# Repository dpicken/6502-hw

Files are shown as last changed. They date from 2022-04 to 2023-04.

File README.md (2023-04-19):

# 6502-hw

Schematics and PCBs for a [Ben Eater](https://eater.net/6502) inspired 6502 computer.

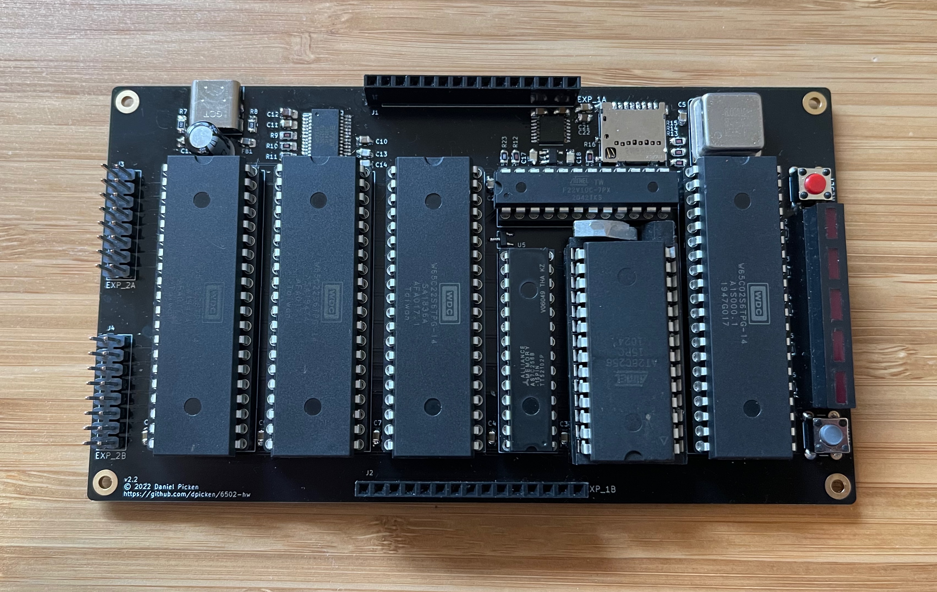
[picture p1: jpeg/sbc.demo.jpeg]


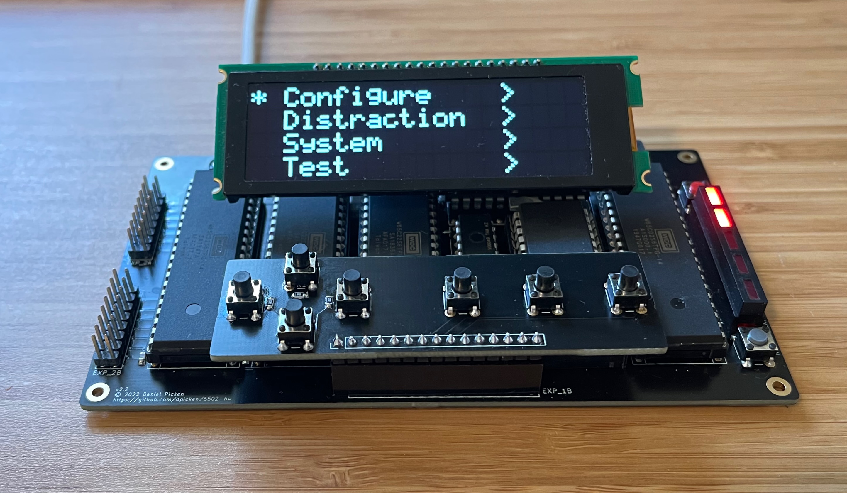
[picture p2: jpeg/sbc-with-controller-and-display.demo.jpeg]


## SBC

The single board computer ([schematic](/pdf/sbc.pdf), [layout](pdf/sbc.pcb.pdf), [BOM](bom/sbc.md)), features include:

  - 65C02 CPU, 8 MHz (with a suitable EEPROM)
  - ATF22V10C PLD (address space decode and IRQ glue)
  - 32 KiB ROM
  - 32 KiB RAM
  - 32 GiB microSD mass storage
  - 3 VIAs (1 system, 2 user accessible)
  - USB serial

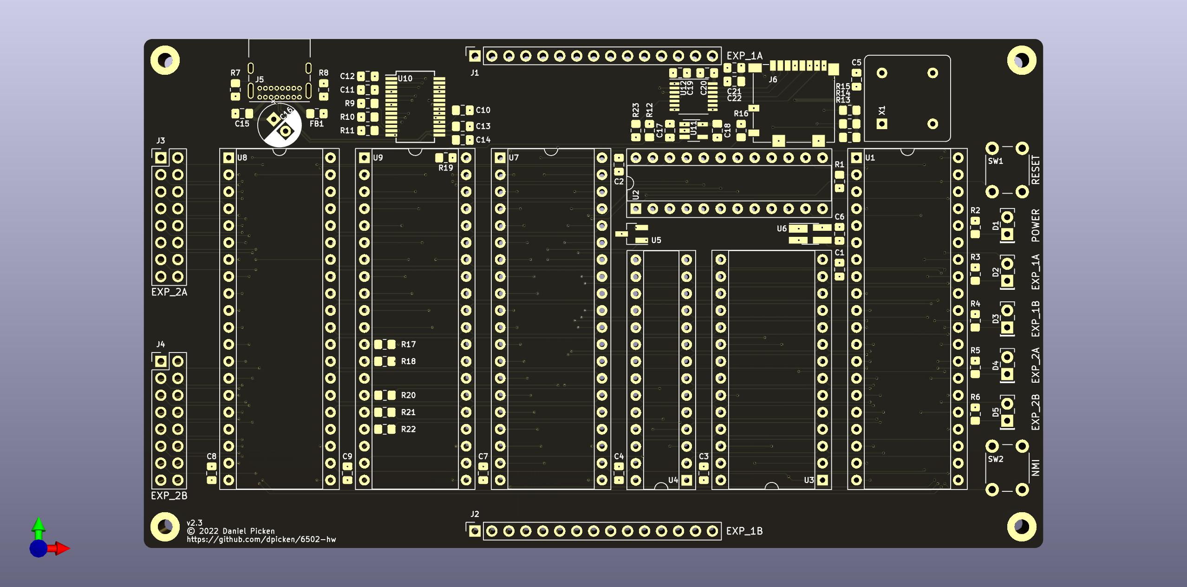
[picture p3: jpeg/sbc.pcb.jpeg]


### Programmable Logic

Install [rust](https://www.rust-lang.org/tools/install), then install galette:

```
git clone https://github.com/simon-frankau/galette
bash -c "cd galette; cargo build --release"
cp galette/target/release/galette ~/bin
```

Clone the fab build system and the 6502-hw project:

```
git clone https://github.com/dpicken/fab
git clone https://github.com/dpicken/6502-hw
```

Build:

```
cd 6502-hw
make
```

Write ATF22v10C:

```
make install
```

### Software

- See [dpicken/6502-os](https://github.com/dpicken/6502-os).

## SBC Controller

A controller for the single board computer ([schematic](/pdf/sbc-exp-control.pdf), [layout](pdf/sbc-exp-control.pcb.pdf), [BOM](bom/sbc-exp-control.md)).

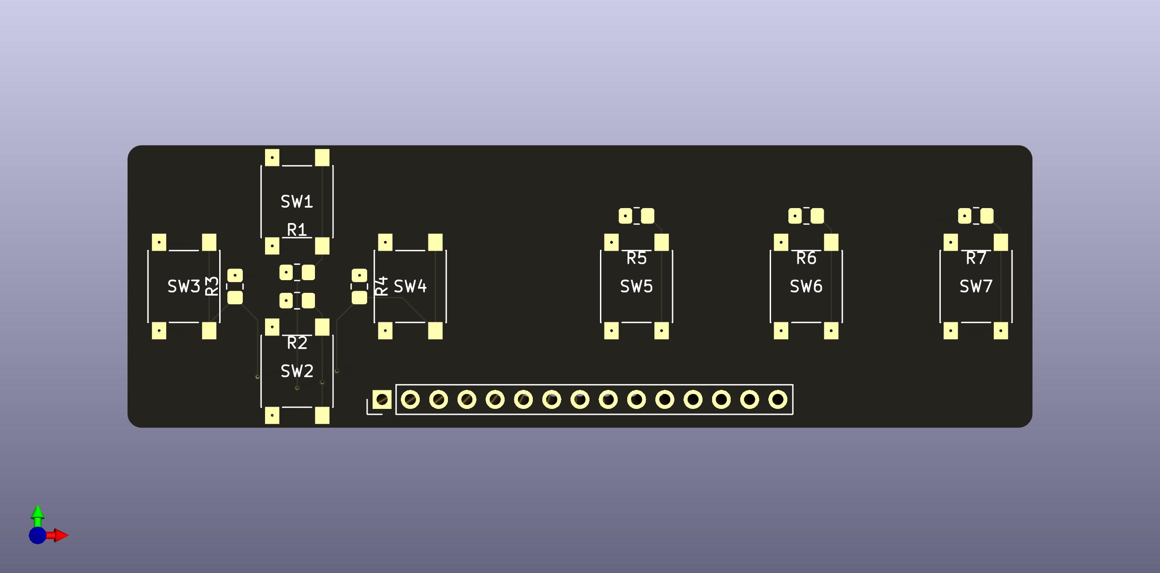
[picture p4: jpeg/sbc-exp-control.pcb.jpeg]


## SBC Display - 20x4 OLED character module

An OLED display for the single board computer ([schematic](/pdf/sbc-exp-nhd_0420cw-interposer.pdf), [layout](pdf/sbc-exp-nhd_0420cw-interposer.pcb.pdf), [BOM](bom/sbc-exp-nhd_0420cw-interposer.md)).

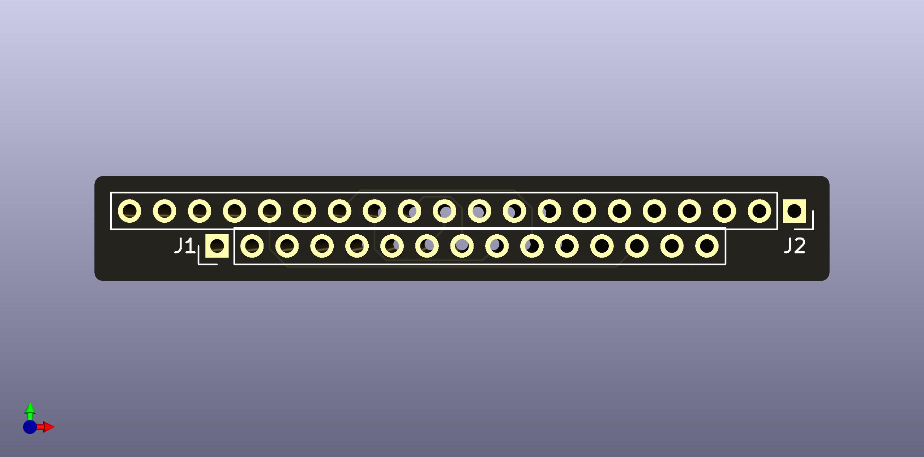
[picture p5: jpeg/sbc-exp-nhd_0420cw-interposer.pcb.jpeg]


## SBC Display - 40x4 or 20x4 LCD character module

An LCD display for the single board computer ([schematic](/pdf/sbc-exp-erm4004_erm2004-interposer.pdf), [layout](pdf/sbc-exp-erm4004_erm2004-interposer.pcb.pdf), [BOM](bom/sbc-exp-erm4004_erm2004-interposer.md)).

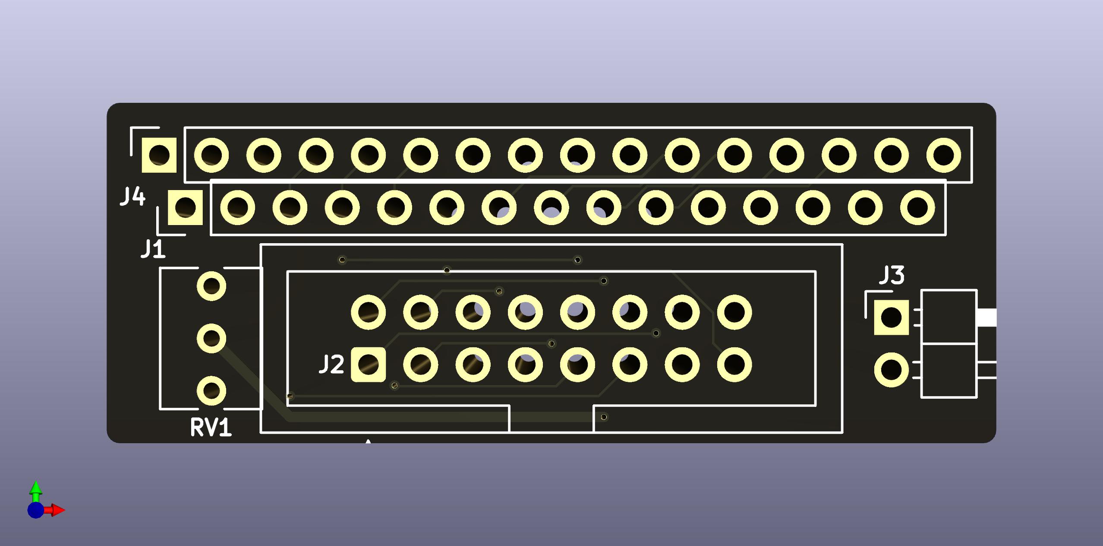
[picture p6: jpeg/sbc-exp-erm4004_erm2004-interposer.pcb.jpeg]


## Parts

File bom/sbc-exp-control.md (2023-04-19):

# SBC Controller BOM

|References|Quantity|Description|
|-|-|-|
|J1|1|1x15 pin header, 2.54mm|
|SW1, SW2, SW3, SW4, SW5, SW6, SW7|7|[6mm tactile switch, SMT](https://www.amazon.com/dp/B07HCFM3H1)|
|R1, R2, R3, R4, R5, R6, R7|7|[1K resistor, 0805](https://www.digikey.com/en/products/detail/cts-resistor-products/77081102P/1000658)|

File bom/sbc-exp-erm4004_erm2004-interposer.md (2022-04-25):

# SBC Display - 40x4 or 20x4 LCD character module BOM

|References|Quantity|Description|
|-|-|-|
|J1|1|1x15 pin header, 2.54mm|
|J2|1|2x8 pin header, 2.54mm|
|J3|1|1x2 pin header, 2.54mm|
|J4|1|1x16 pin socket, 2.54mm|
|V0|1|[10K potentiometer](https://www.digikey.com/en/products/detail/tt-electronics-bi/91WR10KLF/6155632)|
||1|[20x4 ERM2004 LCD character module](https://www.buydisplay.com/small-size-blue-lcd-bezel-20x4-arduino-library-character-display-module)|
||1|[40x4 ERM4004 LCD character module](https://www.buydisplay.com/character-arduino-40x4-lcd-display-datasheet-ks0066-white-on-blue)||
||1|1x16 pin header, 2.54mm, for ERM2004|
||1|[2 pin female to female ribbon cable, 2.54mm](https://www.amazon.com/gp/product/B07FM73YN9), for ERM4004|
||1|[16 pin female to female IDC ribbon cable, 2.54mm](https://www.amazon.com/gp/product/B07FKRYJVR), for ERM4004||

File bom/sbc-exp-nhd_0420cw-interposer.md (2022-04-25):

# SBC Display - 20x4 OLED character module BOM

|References|Quantity|Description|
|-|-|-|
|J1|1|1x15 pin header, 2.54mm|
|J2|1|1x20 pin socket, 2.54mm|
|-|1|[20x4 NHD-0402CW OLED character module](https://www.digikey.com/en/products/detail/newhaven-display-intl/NHD-0420CW-AW3/7942051)|
|-|1|1x20 pin header, 2.54mm, for NHD-0420CW|

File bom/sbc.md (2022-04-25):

# SBC BOM

|References|Quantity|Description|
|-|-|-|
|C1, C3, C4, C5, C6, C7, C8, C9, C10, C11, C19, C20, C21|13|[0.1uF MLCC capacitor, 0805](https://www.mouser.com/ProductDetail/80-C0805C104J1RECAUT)|
|C2|1|[0.22uF MLCC capacitor, 0805](https://www.mouser.com/ProductDetail/80-C0805C224J1RECAUT)|
|C12, C22|2|[4.7uF MLCC capacitor, 0805](https://www.mouser.com/ProductDetail/80-C0805C475K3RAUTO)|
|C13, C14|2|[47pF MLCC capacitor, 0805](https://www.mouser.com/ProductDetail/80-C0805C470J1GAUTO)|
|C15|1|[10nF MLCC capacitor, 0805](https://www.mouser.com/ProductDetail/80-C0805C103J1GECTU)|
|C16|1|[220uF electrolytic capacitor, 6.3mm](https://www.digikey.com/en/products/detail/panasonic-electronic-components/ECE-A0JKA221/44725)|
|C17, C18|2|[1uF MLCC capacitor, 0805](https://www.mouser.com/ProductDetail/80-C0805C105K5R)|
|D1, D2, D3, D4, D5|1|[5 segment LED array](https://www.mouser.com/ProductDetail/Lumex/SSA-LXB525ID?qs=K%252Bxkc0srH7Bjt6LUAQzTgQ%3D%3D)|
|FB1|1|[Ferrite Bead, 0805](https://www.mouser.com/ProductDetail/652-MH2029-400Y)|
|J1, J2|2|[1x15 pin socket, 2.54mm](https://www.amazon.com/gp/product/B07VP63Z78)|
|J3, J4|2|[2x8 pin header, 2.54mm](https://www.mouser.com/ProductDetail/649-67996-416HLF)|
|J5|1|[USB Type-C receptacle](https://www.mouser.com/ProductDetail/640-USB4085-GF-A)|
|J6|1|[microSD socket](https://www.mouser.com/ProductDetail/538-104031-0811)|
|R1|1|[3K resistor, 0805](https://www.mouser.com/ProductDetail/667-ERJ-P06J302V)|
|R2, R3, R4, R5, R6|5|[150R resistor, 0805](https://www.mouser.com/ProductDetail/667-ERJ-P06F1600V)|
|R7, R8|2|[5.1K resistor, 0805](https://www.mouser.com/ProductDetail/667-ERJ-P06J512V)|
|R9, R10, R11, R12, R13, R14, R15, R16|8|[10K resistor, 0805](https://www.mouser.com/ProductDetail/667-ERJ-UP6J103V)|
|R17, R18, R19, R20, R21, R22, R23|7|[30R resistor, 0805](https://www.mouser.com/ProductDetail/667-ERJ-P06J330V)|
|SW1|1|[6mm tactile switch, red](https://www.digikey.com/en/products/detail/c-k/PTS645SK43-2-LFS/1146784)|
|SW2|1|[6mm tactile switch, gray](https://www.digikey.com/en/products/detail/c-k/PTS645SH43-2-LFS/3861368)|
|U1|1|[WD65C02](https://www.jameco.com/z/W65C02S6TPG-14-Western-Design-Center-MPU-8-Bit-14MHz-65KB-Memory-40-Pin-PDIP_2143638.html), [IC socket](https://www.mouser.com/ProductDetail/575-199640)|
|U2|1|[ATF22V10C-7PX](https://www.mouser.com/ProductDetail/556-AF22V10C7PX), [IC socket](https://www.mouser.com/ProductDetail/80-C0805C105K5R)|
|U3|1|[AT28C256-15PU](https://www.digikey.com/en/products/detail/microchip-technology/AT28C256-15PU/1008506), [IC socket](https://www.mouser.com/ProductDetail/575-199628)|
|U4|1|[AS7C256B-15PIN](https://www.digikey.com/en/products/detail/alliance-memory-inc/AS7C256B-15PIN/4498986), [IC socket](https://www.mouser.com/ProductDetail/575-199328)|
|U5|1|[DS1813R](https://www.mouser.com/ProductDetail/700-DS1813R-5TR)|
|U6|1|[MAX6816](https://www.ebay.com/itm/10pcs-MAX6816EUS-T-MAX-6816-EUS-T-Integrated-Circuit-IC-/174489807094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)|
|U7, U8, U9|3|[WD65C22](https://www.jameco.com/z/W65C22S6TPG-14-Western-Design-Center-Versatile-Interface-Adapter-via-8-Bit-I-O-Ports-14-MHz-40-Pin-PDIP-CMOS-5-Volt_2143591.html), [IC socket](https://www.mouser.com/ProductDetail/575-199640)|
|U10|1|[RT245RL](https://www.mouser.com/ProductDetail/895-FT245RL-TUBE)|
|U11|1|[LD39015M33R](https://www.mouser.com/ProductDetail/511-LD39015M33R)|
|U12|1|[TXU0304PWR](https://www.mouser.com/ProductDetail/595-TXU0304PWR)|
|X1|1|[8MHz oscillator, half-can](https://www.mouser.com/ProductDetail/520-TCH800-X)|

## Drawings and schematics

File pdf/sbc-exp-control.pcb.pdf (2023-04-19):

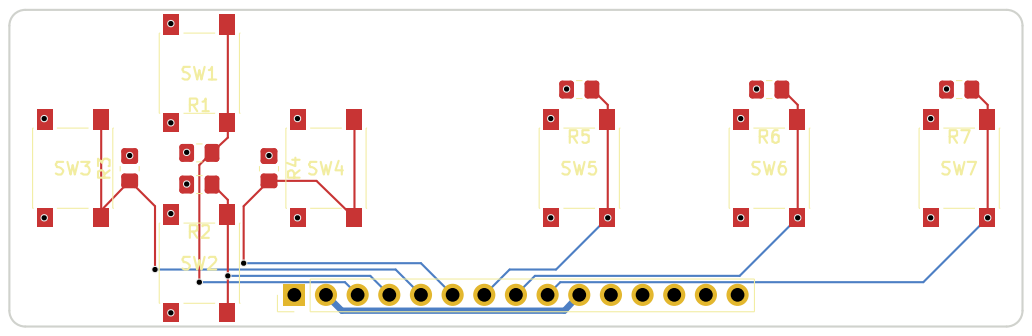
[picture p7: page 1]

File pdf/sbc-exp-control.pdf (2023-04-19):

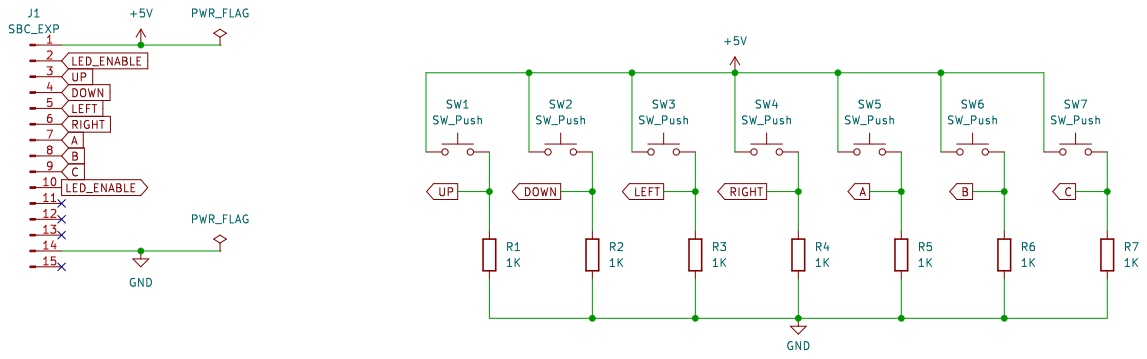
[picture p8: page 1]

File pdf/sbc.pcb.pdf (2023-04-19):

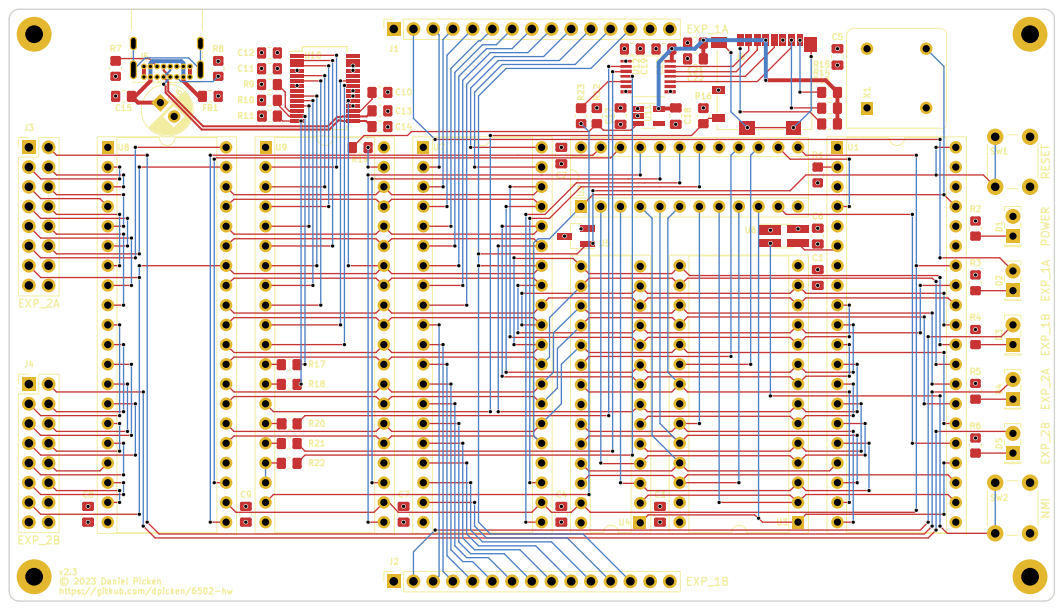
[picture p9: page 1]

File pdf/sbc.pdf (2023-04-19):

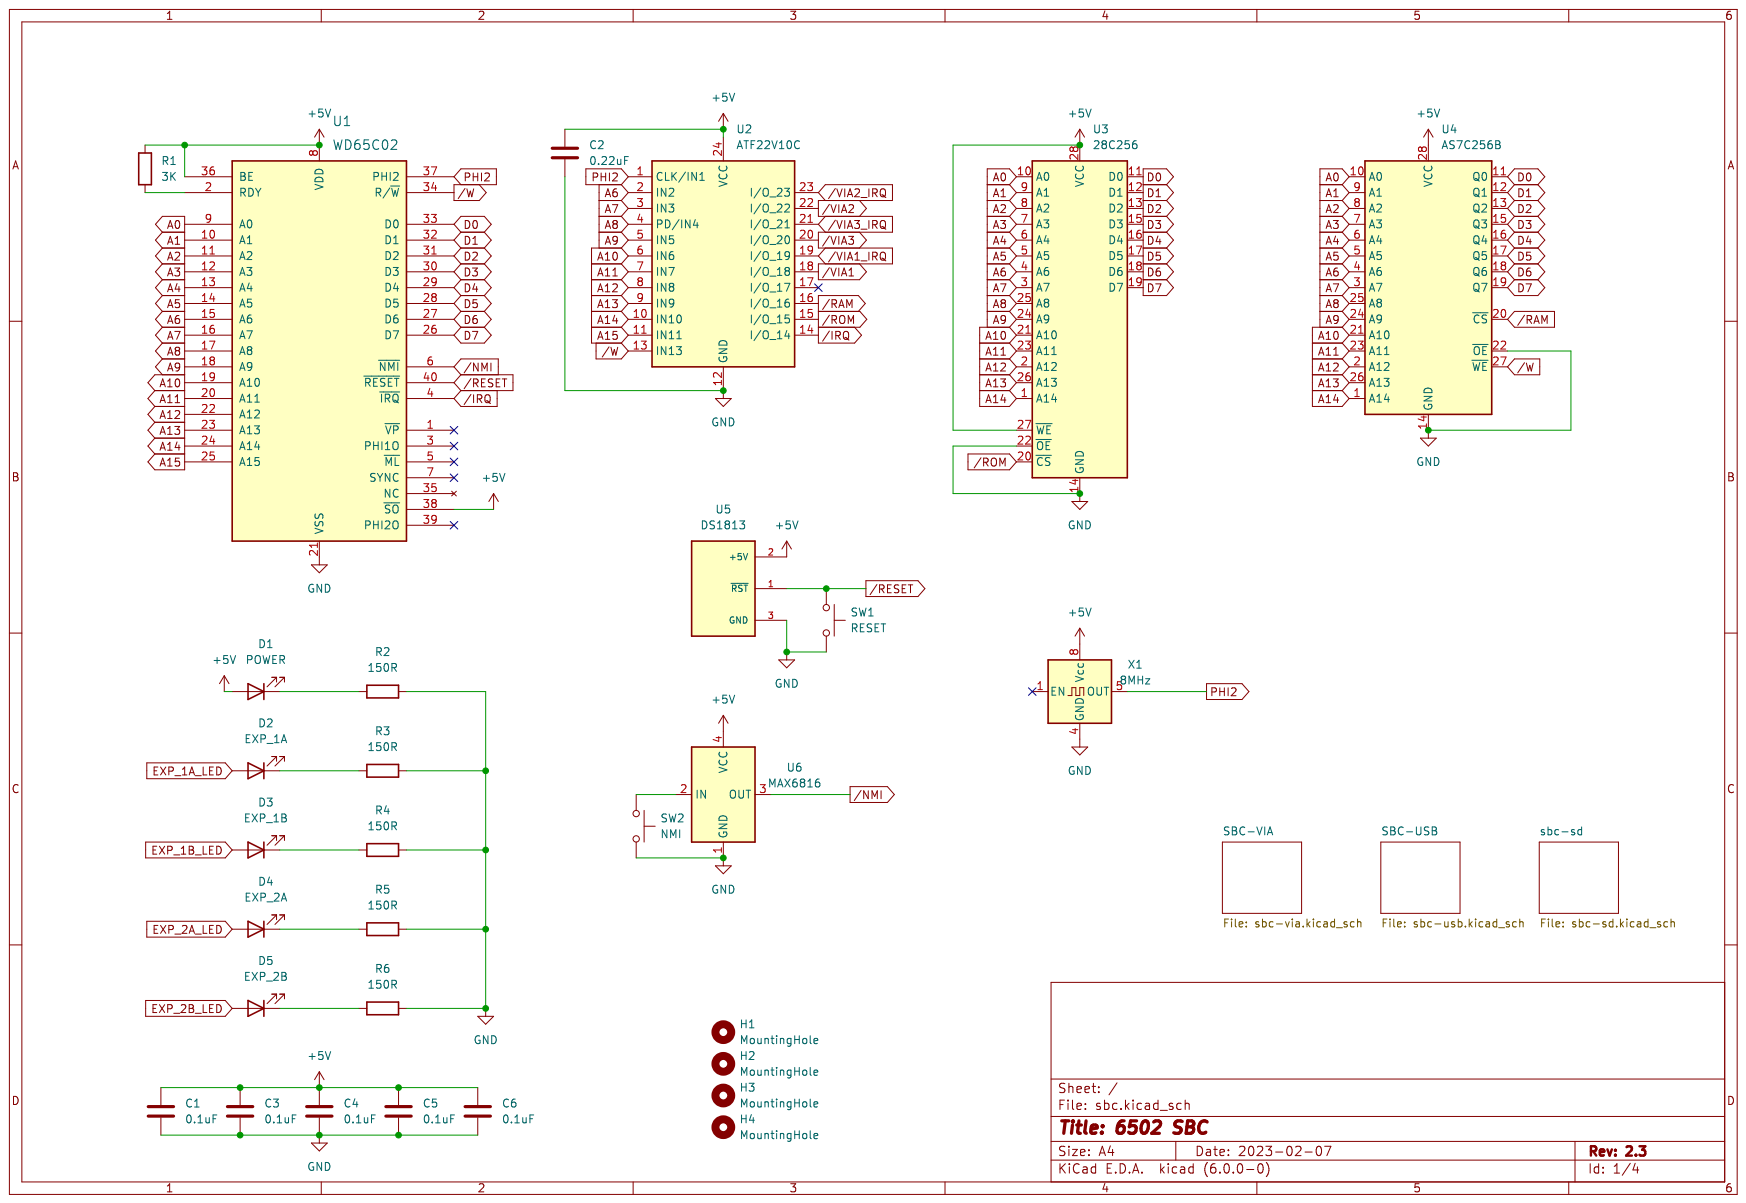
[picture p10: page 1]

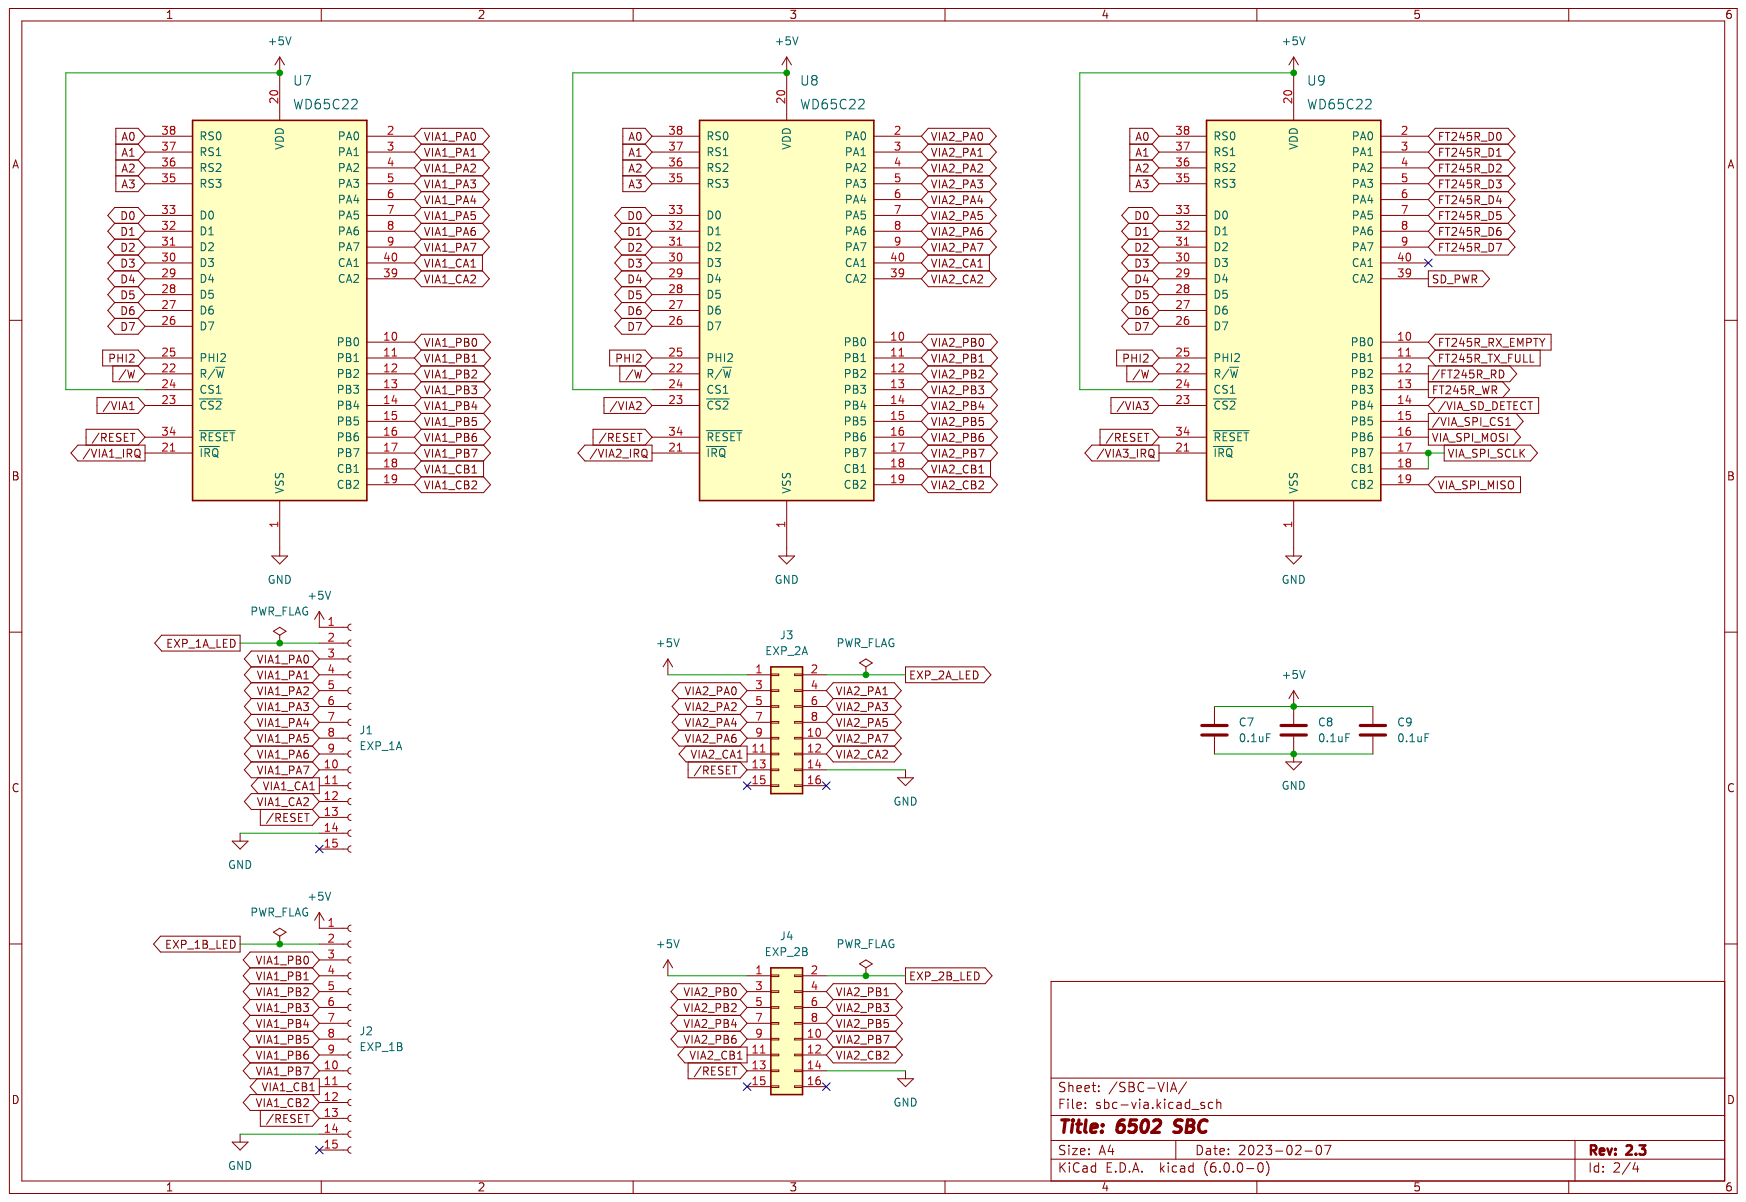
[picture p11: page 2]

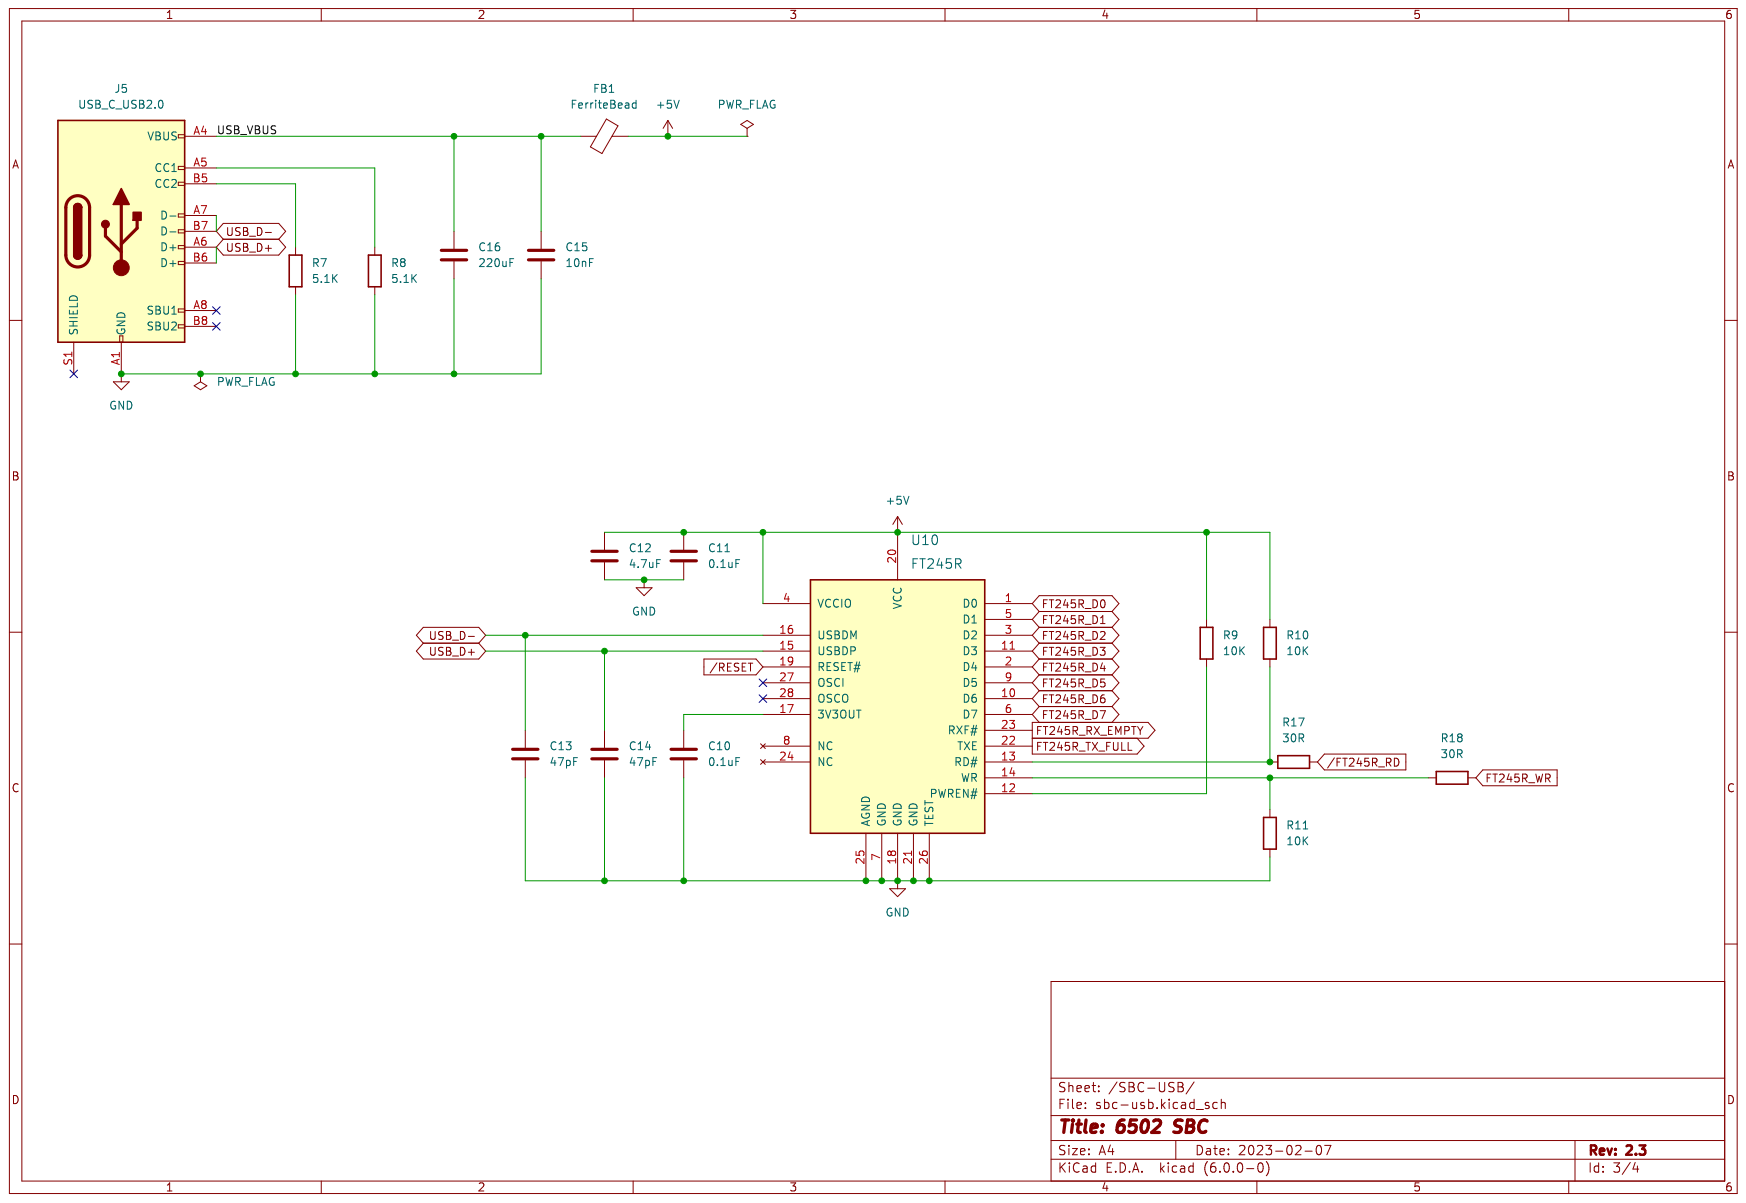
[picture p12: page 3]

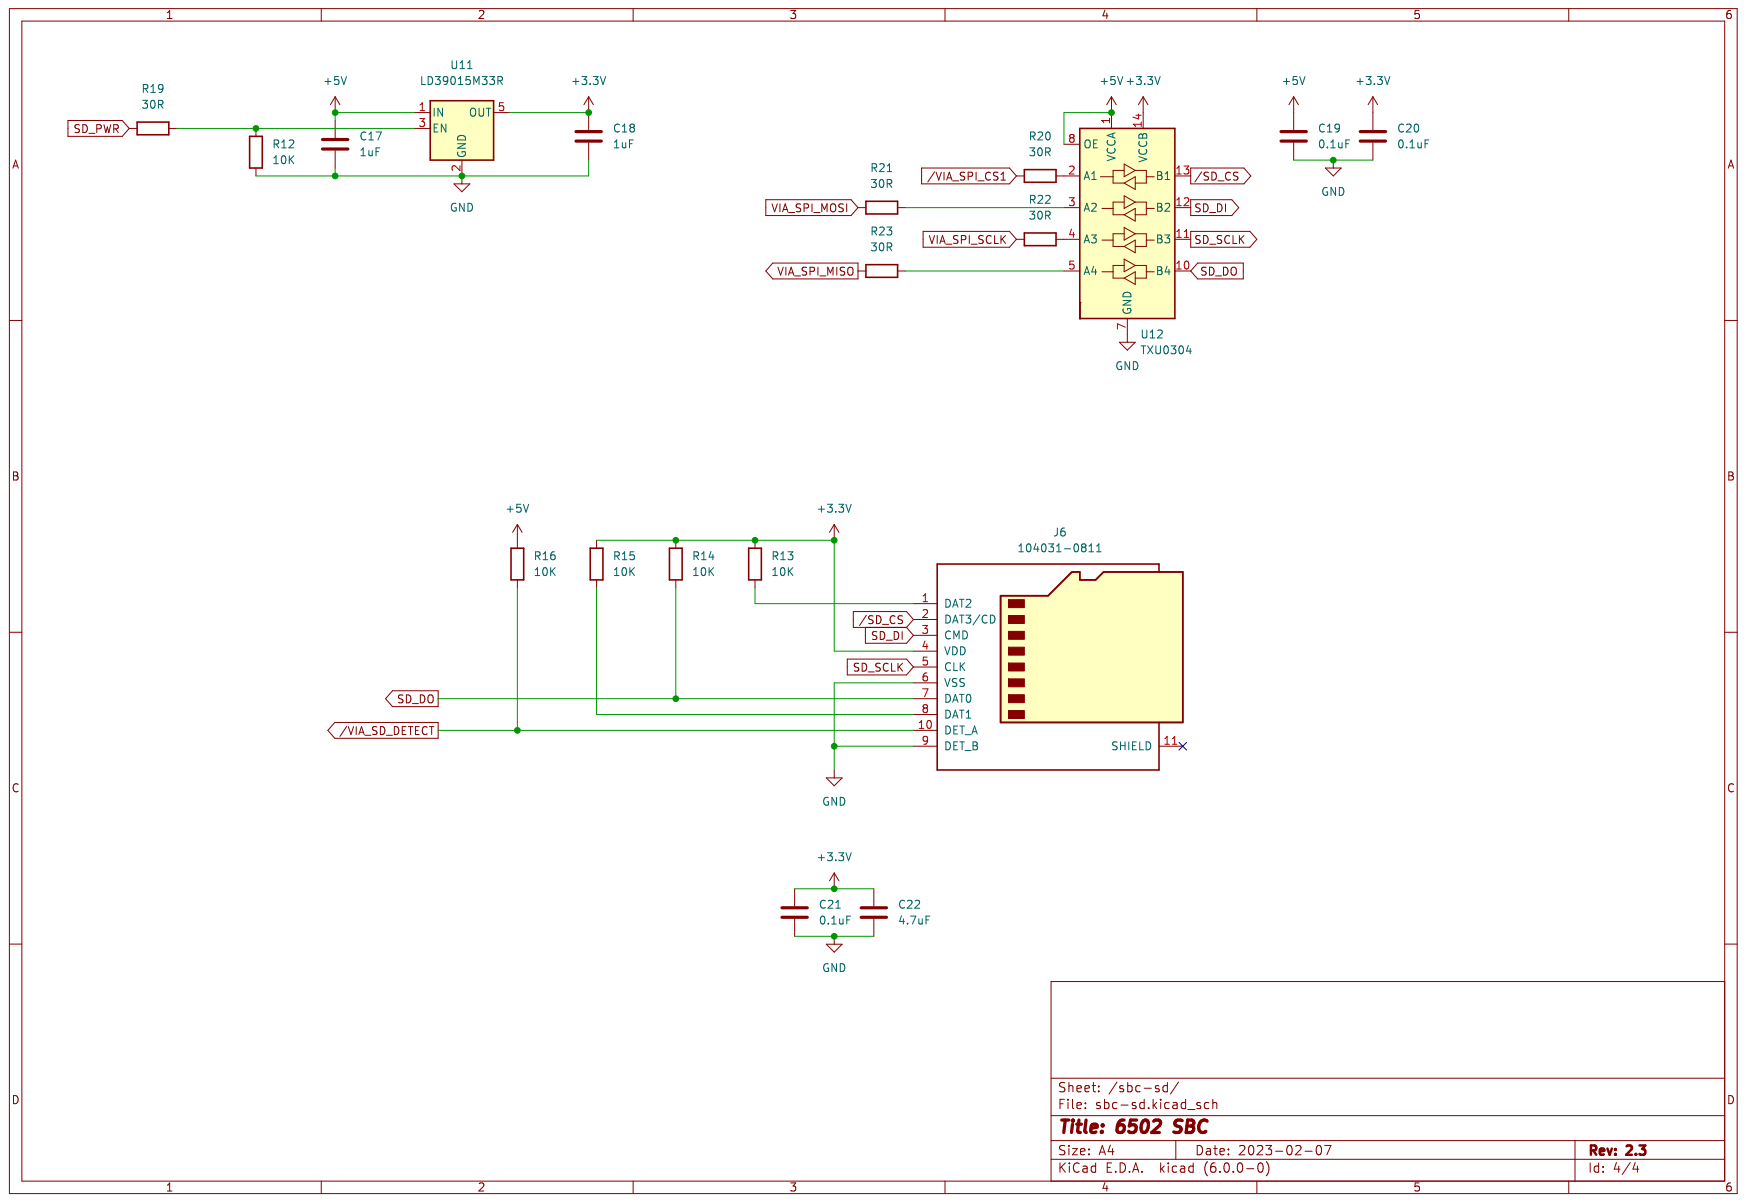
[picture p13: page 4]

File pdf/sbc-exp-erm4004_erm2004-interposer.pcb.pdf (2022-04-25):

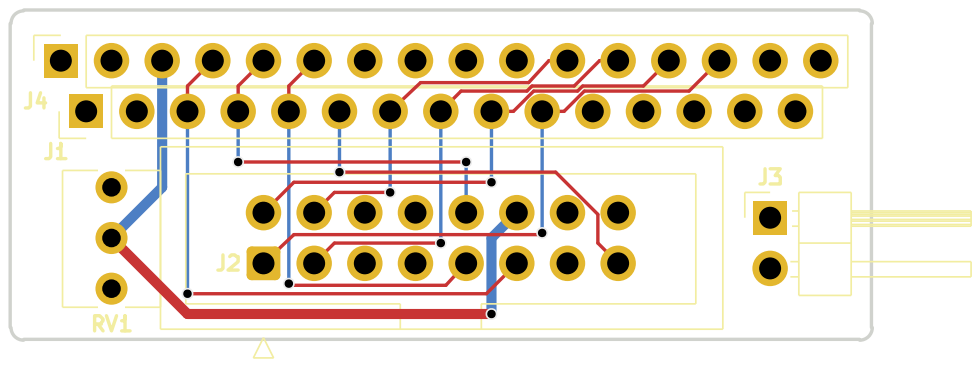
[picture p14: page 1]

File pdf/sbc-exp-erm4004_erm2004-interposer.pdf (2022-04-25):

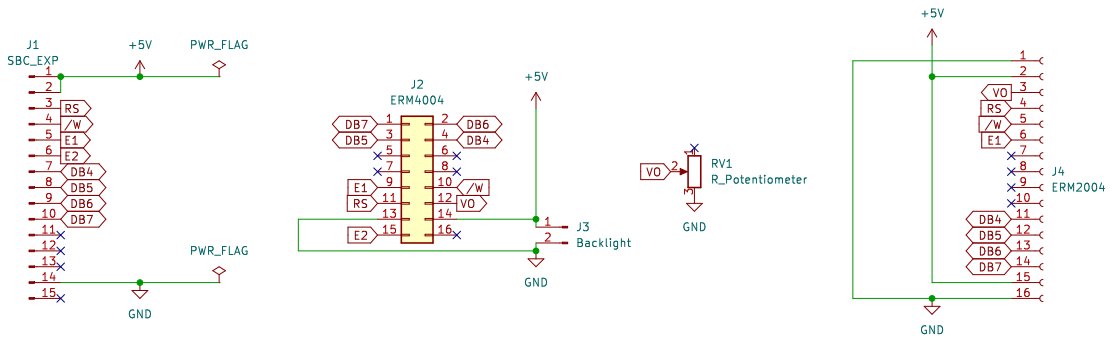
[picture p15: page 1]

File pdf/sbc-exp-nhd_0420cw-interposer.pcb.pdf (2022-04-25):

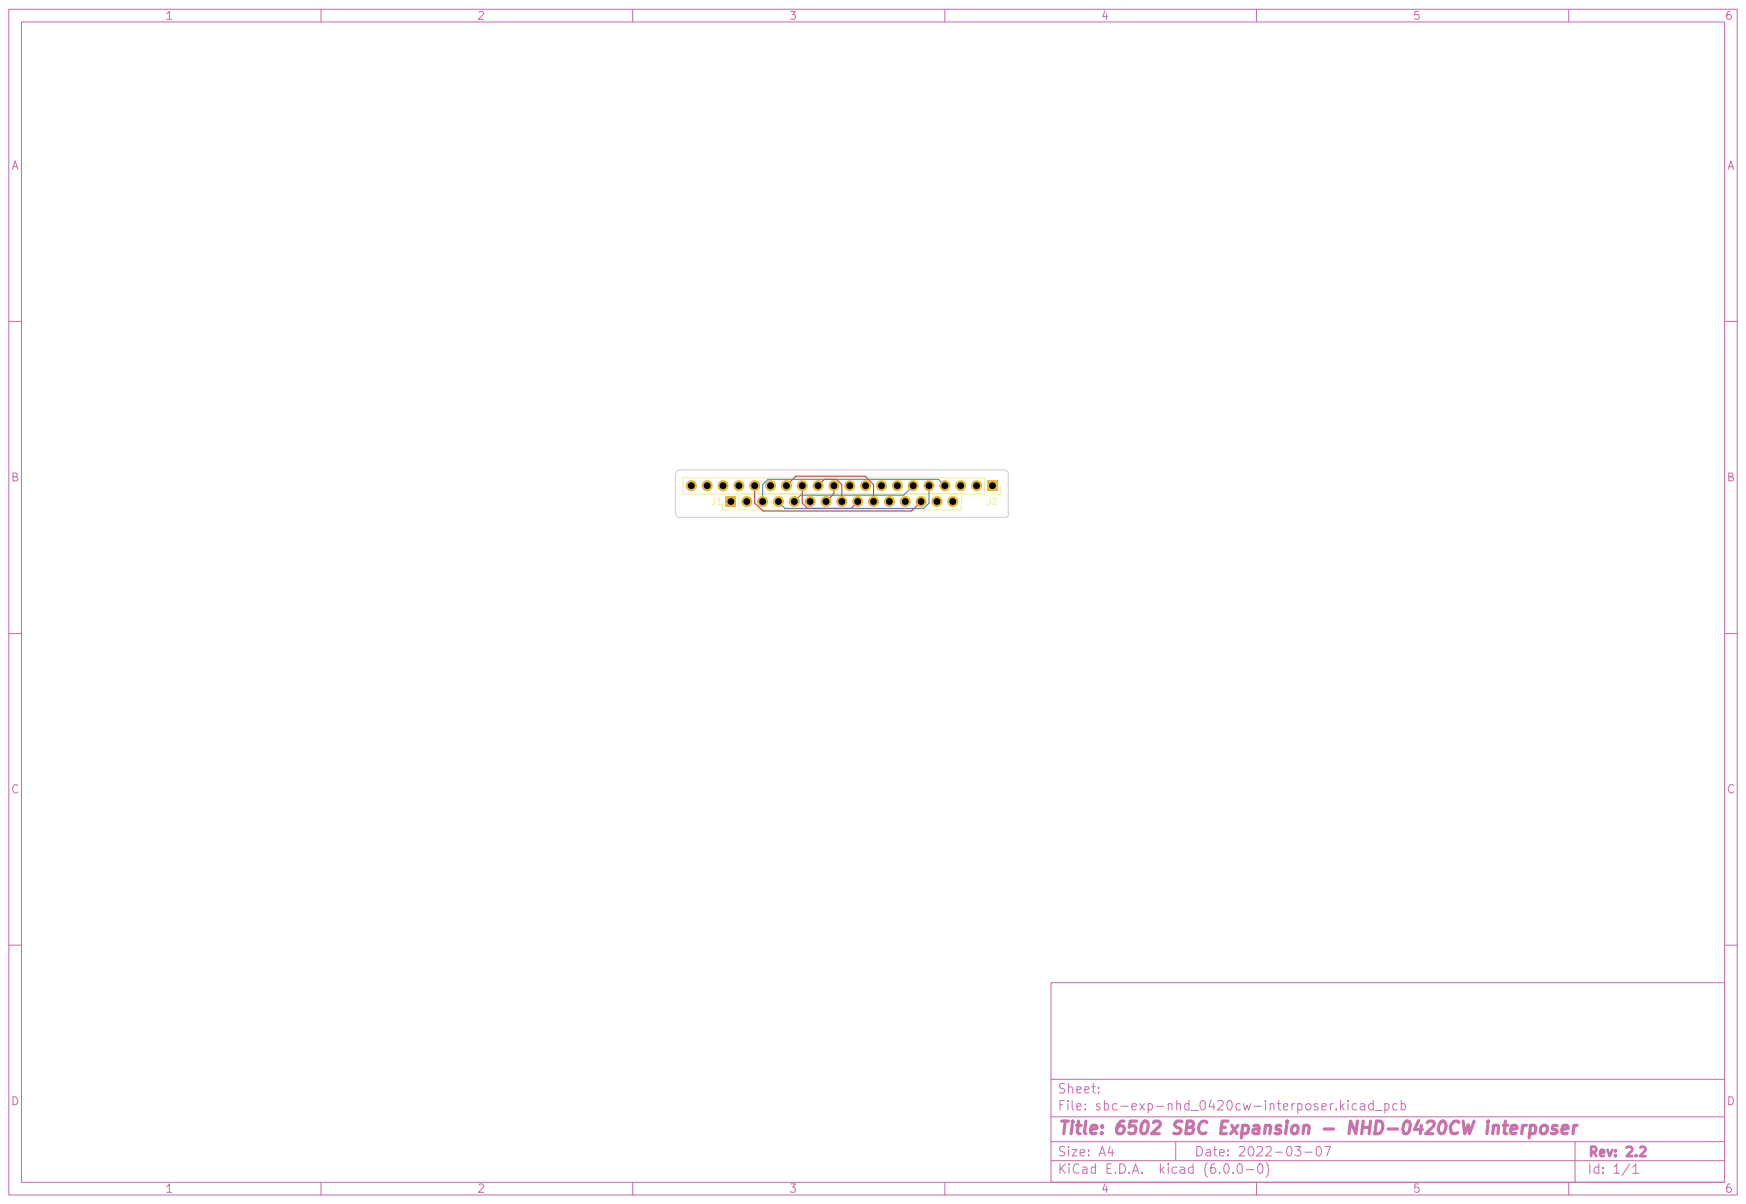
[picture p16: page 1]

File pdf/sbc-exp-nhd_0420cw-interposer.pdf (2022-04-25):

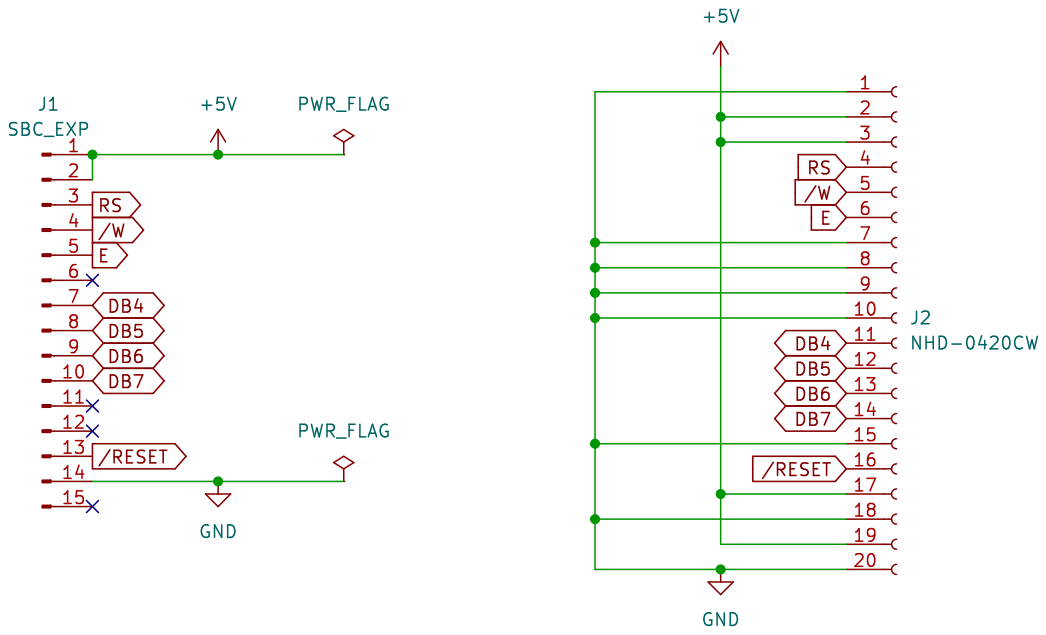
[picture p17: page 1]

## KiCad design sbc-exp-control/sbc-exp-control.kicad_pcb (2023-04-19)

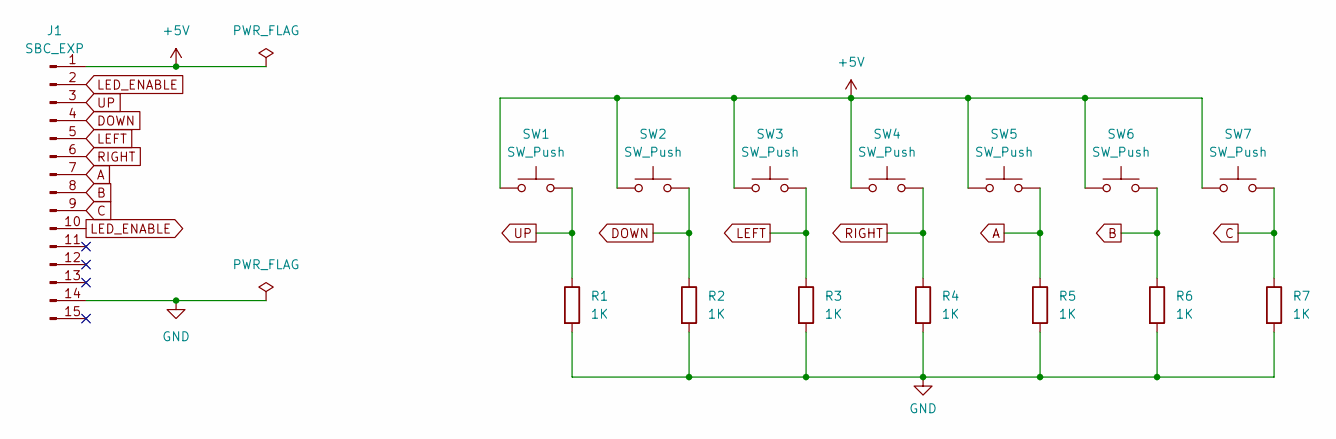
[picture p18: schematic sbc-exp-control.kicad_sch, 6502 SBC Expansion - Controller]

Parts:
J1: SBC_EXP; PinHeader_1x15_P2.54mm_Vertical
R1, R2, R3, R4, R5, R6, R7: 1K; R_0805_2012Metric_Pad1.20x1.40mm_HandSolder
SW1, SW2, SW3, SW4, SW5, SW6, SW7: SW_Push; SW_Push_1P1T_NO_6x6mm_H9.5mm

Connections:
+5V: J1.1, SW1.1, SW2.1, SW3.1, SW4.1, SW5.1, SW6.1, SW7.1
A: J1.7, R5.1, SW5.2
B: J1.8, R6.1, SW6.2
C: J1.9, R7.1, SW7.2
DOWN: J1.4, R2.1, SW2.2
GND: J1.14, R1.2, R2.2, R3.2, R4.2, R5.2, R6.2, R7.2
LED_ENABLE: J1.2, J1.10
LEFT: J1.5, R3.1, SW3.2
RIGHT: J1.6, R4.1, SW4.2
UP: J1.3, R1.1, SW1.2

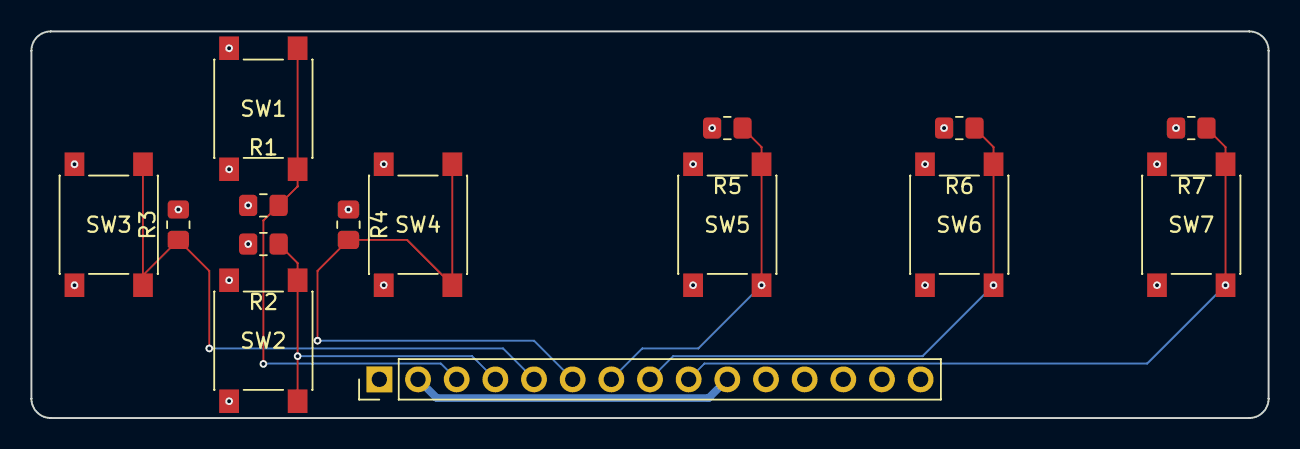
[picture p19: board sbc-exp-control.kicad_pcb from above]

Board: 4 copper layers, 81.3 x 25.4 mm, 15 parts (0 on the bottom side), 10 nets.

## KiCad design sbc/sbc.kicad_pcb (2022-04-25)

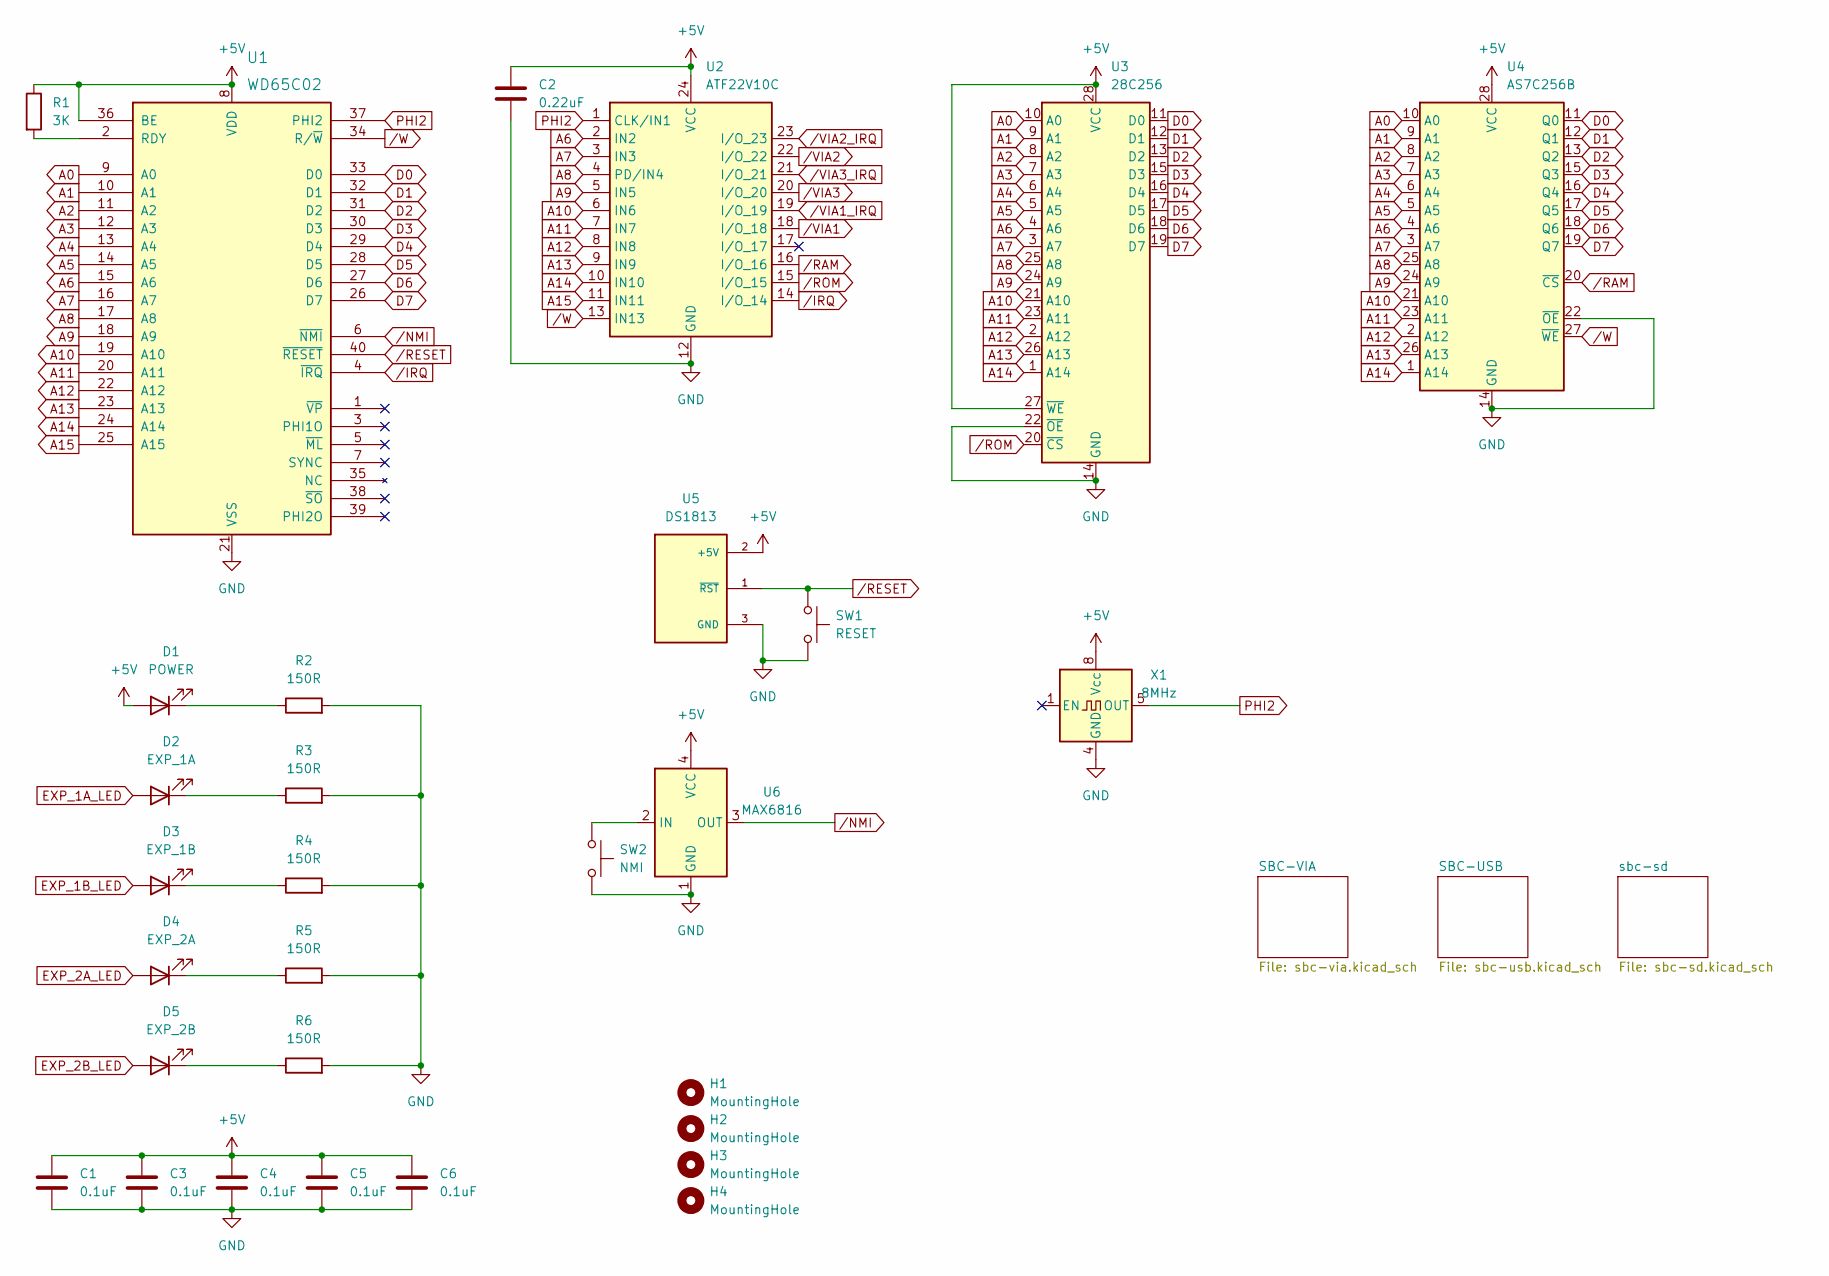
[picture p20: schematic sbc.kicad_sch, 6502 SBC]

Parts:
C1, C3, C4, C5, C6: 0.1uF; C_0805_2012Metric_Pad1.18x1.45mm_HandSolder
C2: 0.22uF; C_0805_2012Metric_Pad1.18x1.45mm_HandSolder
D1: POWER; LED_Rectangular_W5.0mm_H2.0mm
D2: EXP_1A; LED_Rectangular_W5.0mm_H2.0mm
D3: EXP_1B; LED_Rectangular_W5.0mm_H2.0mm
D4: EXP_2A; LED_Rectangular_W5.0mm_H2.0mm
D5: EXP_2B; LED_Rectangular_W5.0mm_H2.0mm
H1, H2, H3, H4: MountingHole; MountingHole_2.2mm_M2_Pad
R1: 3K; R_0805_2012Metric_Pad1.20x1.40mm_HandSolder
R2, R3, R4, R5, R6: 150R; R_0805_2012Metric_Pad1.20x1.40mm_HandSolder
SW1: RESET; SW_PUSH_6mm_H4.3mm
SW2: NMI; SW_PUSH_6mm_H4.3mm
U1: WD65C02; DIP-40_W15.24mm_Socket
U2: ATF22V10C; DIP-24_W7.62mm_Socket
U3: 28C256; DIP-28_W15.24mm_Socket
U4: AS7C256B; DIP-28_W7.62mm_Socket
U5: DS1813; SOT-23_Handsoldering
U6: MAX6816; SOT-143_Handsoldering
X1: 8MHz; Oscillator_DIP-8

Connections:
+5V: C1.1, C2.1, C3.1, C4.1, C5.1, C6.1, D1.2 (A), R1.1, U1.8 (VDD), U1.36 (BE), U2.24 (VCC), U3.27 (~WE), U3.28 (VCC), U4.28 (VCC), U5.2 (+5V), U6.4 (VCC), X1.8 (Vcc); also elsewhere on the board
A0: U1.9 (A0), U3.10 (A0), U4.10 (A0); also elsewhere on the board
A1: U1.10 (A1), U3.9 (A1), U4.9 (A1); also elsewhere on the board
A2: U1.11 (A2), U3.8 (A2), U4.8 (A2); also elsewhere on the board
A3: U1.12 (A3), U3.7 (A3), U4.7 (A3); also elsewhere on the board
A4: U1.13 (A4), U3.6 (A4), U4.6 (A4)
A5: U1.14 (A5), U3.5 (A5), U4.5 (A5)
A6: U1.15 (A6), U2.2 (IN2), U3.4 (A6), U4.4 (A6)
A7: U1.16 (A7), U2.3 (IN3), U3.3 (A7), U4.3 (A7)
A8: U1.17 (A8), U2.4 (PD/IN4), U3.25 (A8), U4.25 (A8)
A9: U1.18 (A9), U2.5 (IN5), U3.24 (A9), U4.24 (A9)
A10: U1.19 (A10), U2.6 (IN6), U3.21 (A10), U4.21 (A10)
A11: U1.20 (A11), U2.7 (IN7), U3.23 (A11), U4.23 (A11)
A12: U1.22 (A12), U2.8 (IN8), U3.2 (A12), U4.2 (A12)
A13: U1.23 (A13), U2.9 (IN9), U3.26 (A13), U4.26 (A13)
A14: U1.24 (A14), U2.10 (IN10), U3.1 (A14), U4.1 (A14)
A15: U1.25 (A15), U2.11 (IN11)
D0: U1.33 (D0), U3.11 (D0), U4.11 (Q0); also elsewhere on the board
D1: U1.32 (D1), U3.12 (D1), U4.12 (Q1); also elsewhere on the board
D2: U1.31 (D2), U3.13 (D2), U4.13 (Q2); also elsewhere on the board
D3: U1.30 (D3), U3.15 (D3), U4.15 (Q3); also elsewhere on the board
D4: U1.29 (D4), U3.16 (D4), U4.16 (Q4); also elsewhere on the board
D5: U1.28 (D5), U3.17 (D5), U4.17 (Q5); also elsewhere on the board
D6: U1.27 (D6), U3.18 (D6), U4.18 (Q6); also elsewhere on the board
D7: U1.26 (D7), U3.19 (D7), U4.19 (Q7); also elsewhere on the board
EXP_1A_LED: D2.2 (A); also elsewhere on the board
EXP_1B_LED: D3.2 (A); also elsewhere on the board
EXP_2A_LED: D4.2 (A); also elsewhere on the board
EXP_2B_LED: D5.2 (A); also elsewhere on the board
GND: C1.2, C2.2, C3.2, C4.2, C5.2, C6.2, R2.2, R3.2, R4.2, R5.2, R6.2, SW1.2, SW2.2, U1.21 (VSS), U2.12 (GND), U3.14 (GND), U3.22 (~OE), U4.14 (GND), U4.22 (~OE), U5.3 (GND), U6.1 (GND), X1.4 (GND); also elsewhere on the board
unnamed: D1.1 (K), R2.1
unnamed: D2.1 (K), R3.1
unnamed: D3.1 (K), R4.1
unnamed: D4.1 (K), R5.1
unnamed: D5.1 (K), R6.1
unnamed: R1.2, U1.2 (RDY)
unnamed: SW2.1, U6.2 (IN)
PHI2: U1.37 (PHI2), U2.1 (CLK/IN1), X1.5 (OUT); also elsewhere on the board
/IRQ: U1.4 (~IRQ), U2.14 (I/O_14)
/NMI: U1.6 (~NMI), U6.3 (OUT)
/RAM: U2.16 (I/O_16), U4.20 (~CS)
/RESET: SW1.1, U1.40 (~RESET), U5.1 (~RST); also elsewhere on the board
/ROM: U2.15 (I/O_15), U3.20 (~CS)
/VIA1: U2.18 (I/O_18); also elsewhere on the board
/VIA1_IRQ: U2.19 (I/O_19); also elsewhere on the board
/VIA2: U2.22 (I/O_22); also elsewhere on the board
/VIA2_IRQ: U2.23 (I/O_23); also elsewhere on the board
/VIA3: U2.20 (I/O_20); also elsewhere on the board
/VIA3_IRQ: U2.21 (I/O_21); also elsewhere on the board
/W: U1.34 (R/~W), U2.13 (IN13), U4.27 (~WE); also elsewhere on the board

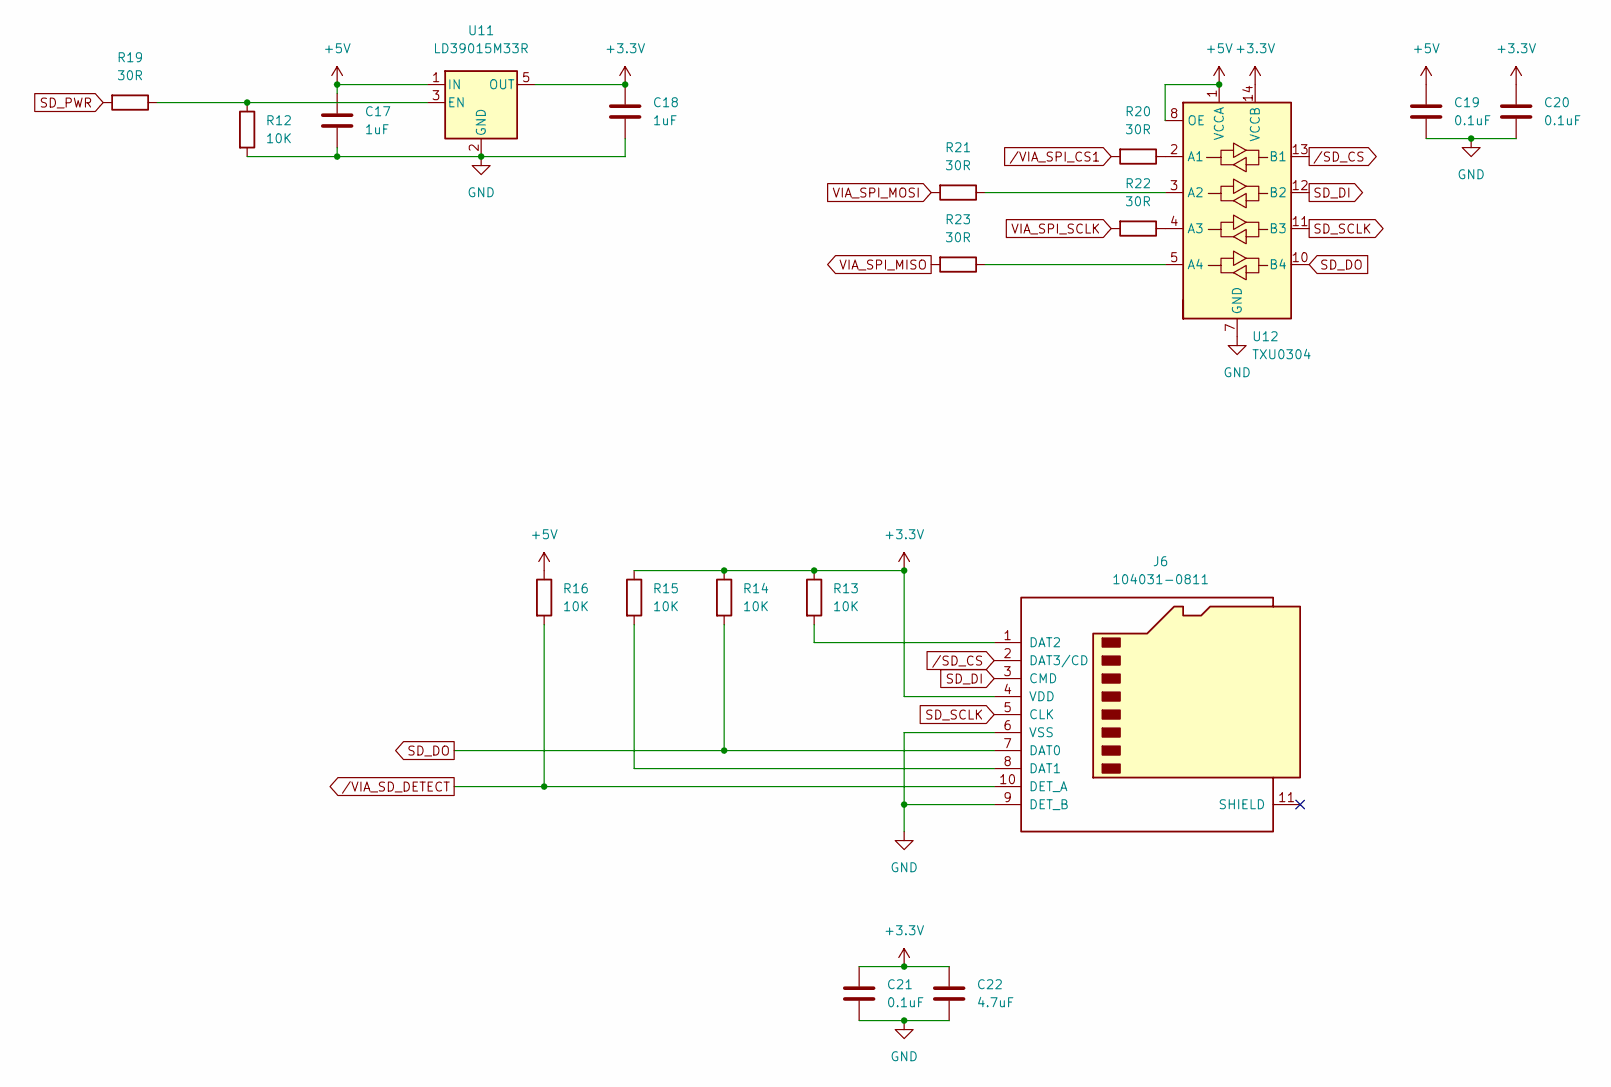
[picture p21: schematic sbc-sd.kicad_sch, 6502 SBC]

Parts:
C17, C18: 1uF; C_0805_2012Metric_Pad1.18x1.45mm_HandSolder
C19, C20, C21: 0.1uF; C_0805_2012Metric_Pad1.18x1.45mm_HandSolder
C22: 4.7uF; C_0805_2012Metric_Pad1.18x1.45mm_HandSolder
J6: 104031-0811; microSD_HC_Molex_104031-0811_HandSoler
R12, R13, R14, R15, R16: 10K; R_0805_2012Metric_Pad1.20x1.40mm_HandSolder
R19, R20, R21, R22, R23: 30R; R_0805_2012Metric_Pad1.20x1.40mm_HandSolder
U11: LD39015M33R; SOT-23-5_HandSoldering
U12: TXU0304; TSSOP-14_4.4x5mm_P0.65mm

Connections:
+3V3: C18.1, C20.1, C21.1, C22.1, J6.4 (VDD), R13.1, R14.1, R15.1, U11.5 (OUT), U12.14 (VCCB)
+5V: C17.1, C19.1, R16.1, U11.1 (IN), U12.1 (VCCA), U12.8 (OE); also elsewhere on the board
GND: C17.2, C18.2, C19.2, C20.2, C21.2, C22.2, J6.6 (VSS), J6.9 (DET_B), R12.2, U11.2 (GND), U12.7 (GND); also elsewhere on the board
unnamed: J6.1 (DAT2), R13.2
unnamed: J6.8 (DAT1), R15.2
unnamed: R12.1, R19.1, U11.3 (EN)
unnamed: R20.1, U12.2 (A1)
unnamed: R21.1, U12.3 (A2)
unnamed: R22.1, U12.4 (A3)
unnamed: R23.1, U12.5 (A4)
SD_DI: J6.3 (CMD), U12.12 (B2)
SD_DO: J6.7 (DAT0), R14.2, U12.10 (B4)
SD_PWR: R19.2; also elsewhere on the board
SD_SCLK: J6.5 (CLK), U12.11 (B3)
VIA_SPI_MISO: R23.2; also elsewhere on the board
VIA_SPI_MOSI: R21.2; also elsewhere on the board
VIA_SPI_SCLK: R22.2; also elsewhere on the board
/SD_CS: J6.2 (DAT3/CD), U12.13 (B1)
/VIA_SD_DETECT: J6.10 (DET_A), R16.2; also elsewhere on the board
/VIA_SPI_CS1: R20.2; also elsewhere on the board

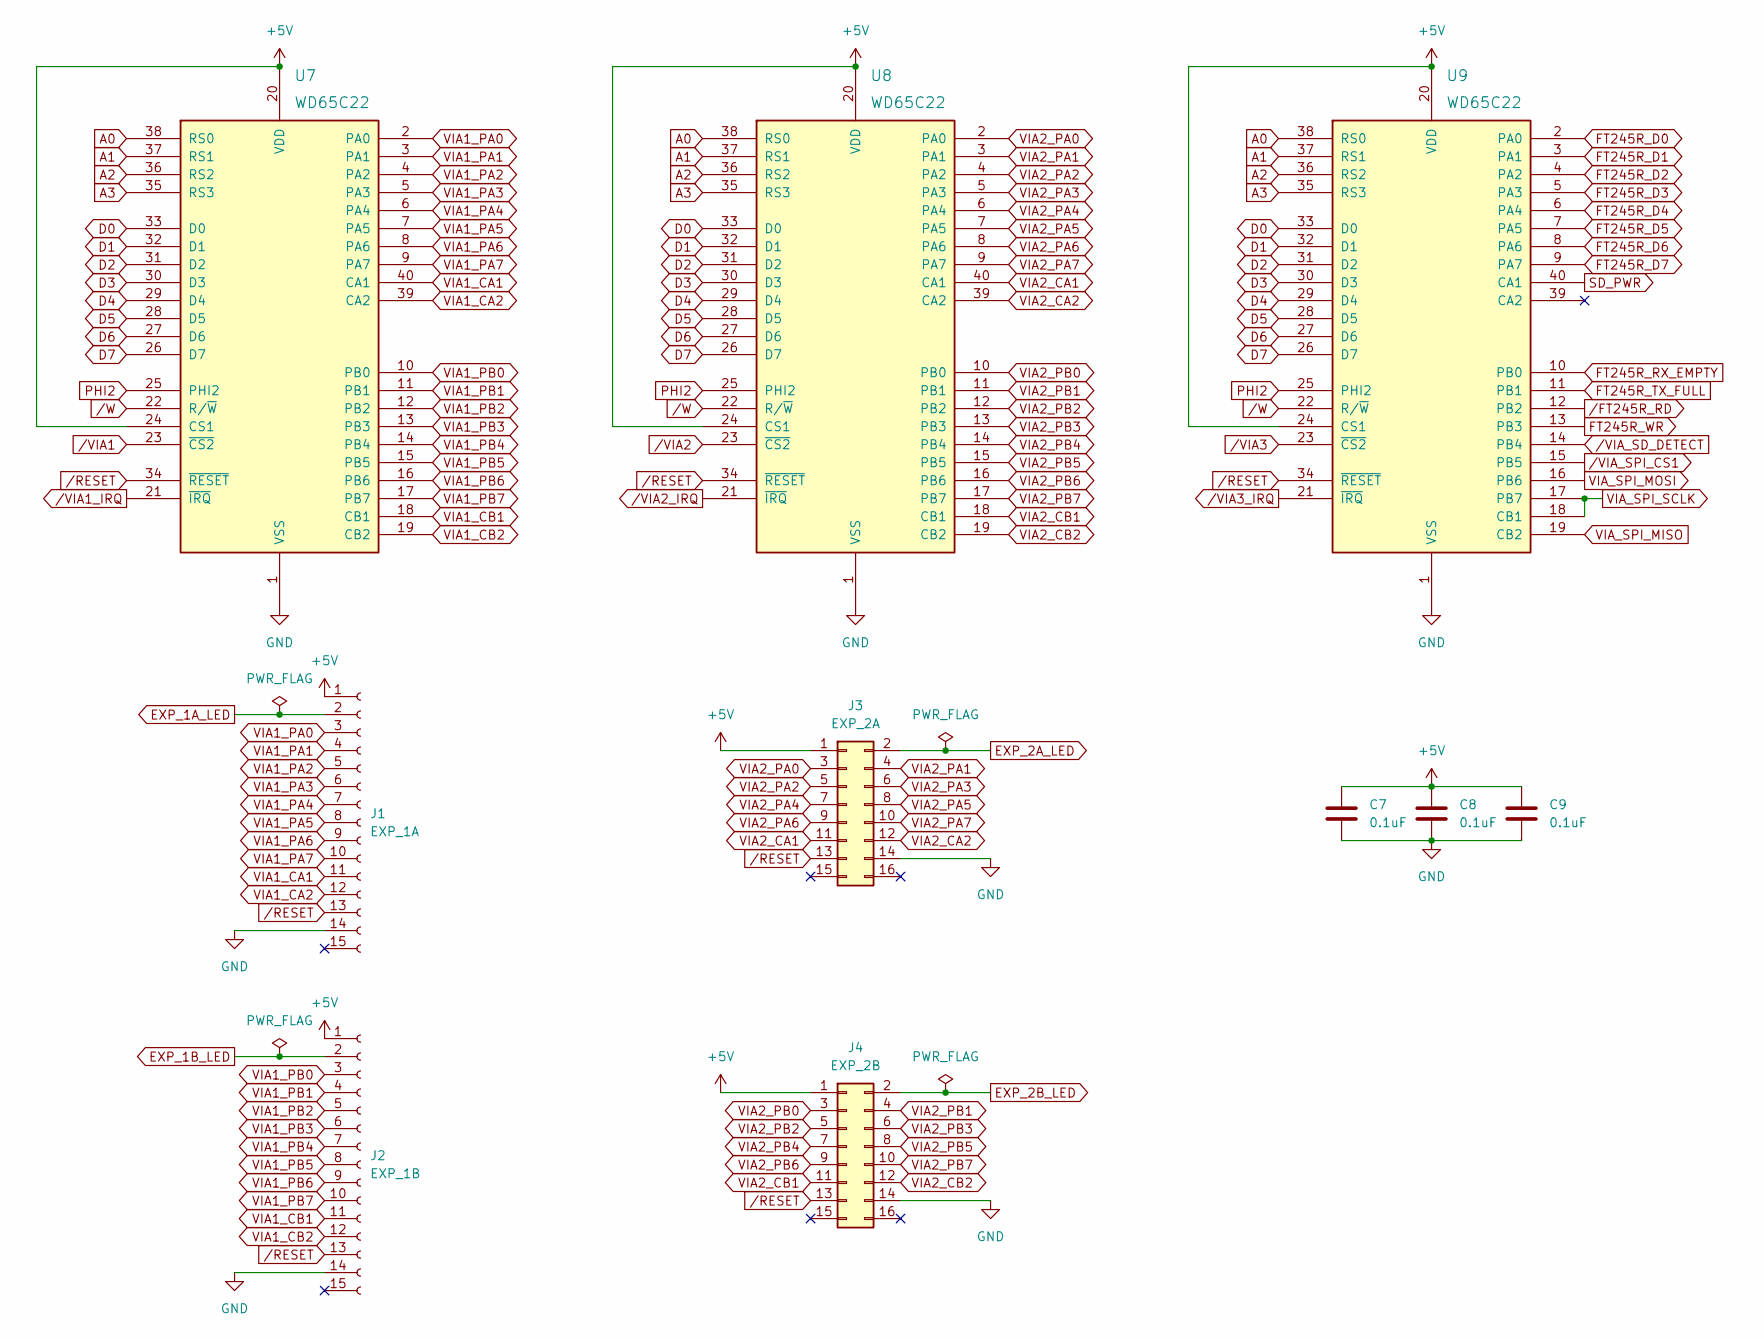
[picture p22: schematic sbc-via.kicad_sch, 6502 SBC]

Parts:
C7, C8, C9: 0.1uF; C_0805_2012Metric_Pad1.18x1.45mm_HandSolder
J1: EXP_1A; PinSocket_1x15_P2.54mm_Vertical
J2: EXP_1B; PinSocket_1x15_P2.54mm_Vertical
J3: EXP_2A; PinHeader_2x08_P2.54mm_Vertical
J4: EXP_2B; PinHeader_2x08_P2.54mm_Vertical
U7, U8, U9: WD65C22; DIP-40_W15.24mm_Socket

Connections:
+5V: C7.1, C8.1, C9.1, J1.1, J2.1, J3.1, J4.1, U7.20 (VDD), U7.24 (CS1), U8.20 (VDD), U8.24 (CS1), U9.20 (VDD), U9.24 (CS1); also elsewhere on the board
A0: U7.38 (RS0), U8.38 (RS0), U9.38 (RS0); also elsewhere on the board
A1: U7.37 (RS1), U8.37 (RS1), U9.37 (RS1); also elsewhere on the board
A2: U7.36 (RS2), U8.36 (RS2), U9.36 (RS2); also elsewhere on the board
A3: U7.35 (RS3), U8.35 (RS3), U9.35 (RS3); also elsewhere on the board
D0: U7.33 (D0), U8.33 (D0), U9.33 (D0); also elsewhere on the board
D1: U7.32 (D1), U8.32 (D1), U9.32 (D1); also elsewhere on the board
D2: U7.31 (D2), U8.31 (D2), U9.31 (D2); also elsewhere on the board
D3: U7.30 (D3), U8.30 (D3), U9.30 (D3); also elsewhere on the board
D4: U7.29 (D4), U8.29 (D4), U9.29 (D4); also elsewhere on the board
D5: U7.28 (D5), U8.28 (D5), U9.28 (D5); also elsewhere on the board
D6: U7.27 (D6), U8.27 (D6), U9.27 (D6); also elsewhere on the board
D7: U7.26 (D7), U8.26 (D7), U9.26 (D7); also elsewhere on the board
EXP_1A_LED: J1.2; also elsewhere on the board
EXP_1B_LED: J2.2; also elsewhere on the board
EXP_2A_LED: J3.2; also elsewhere on the board
EXP_2B_LED: J4.2; also elsewhere on the board
FT245R_D0: U9.2 (PA0); also elsewhere on the board
FT245R_D1: U9.3 (PA1); also elsewhere on the board
FT245R_D2: U9.4 (PA2); also elsewhere on the board
FT245R_D3: U9.5 (PA3); also elsewhere on the board
FT245R_D4: U9.6 (PA4); also elsewhere on the board
FT245R_D5: U9.7 (PA5); also elsewhere on the board
FT245R_D6: U9.8 (PA6); also elsewhere on the board
FT245R_D7: U9.9 (PA7); also elsewhere on the board
FT245R_RX_EMPTY: U9.10 (PB0); also elsewhere on the board
FT245R_TX_FULL: U9.11 (PB1); also elsewhere on the board
FT245R_WR: U9.13 (PB3); also elsewhere on the board
GND: C7.2, C8.2, C9.2, J1.14, J2.14, J3.14, J4.14, U7.1 (VSS), U8.1 (VSS), U9.1 (VSS); also elsewhere on the board
PHI2: U7.25 (PHI2), U8.25 (PHI2), U9.25 (PHI2); also elsewhere on the board
SD_PWR: U9.40 (CA1); also elsewhere on the board
VIA1_CA1: J1.11, U7.40 (CA1)
VIA1_CA2: J1.12, U7.39 (CA2)
VIA1_CB1: J2.11, U7.18 (CB1)
VIA1_CB2: J2.12, U7.19 (CB2)
VIA1_PA0: J1.3, U7.2 (PA0)
VIA1_PA1: J1.4, U7.3 (PA1)
VIA1_PA2: J1.5, U7.4 (PA2)
VIA1_PA3: J1.6, U7.5 (PA3)
VIA1_PA4: J1.7, U7.6 (PA4)
VIA1_PA5: J1.8, U7.7 (PA5)
VIA1_PA6: J1.9, U7.8 (PA6)
VIA1_PA7: J1.10, U7.9 (PA7)
VIA1_PB0: J2.3, U7.10 (PB0)
VIA1_PB1: J2.4, U7.11 (PB1)
VIA1_PB2: J2.5, U7.12 (PB2)
VIA1_PB3: J2.6, U7.13 (PB3)
VIA1_PB4: J2.7, U7.14 (PB4)
VIA1_PB5: J2.8, U7.15 (PB5)
VIA1_PB6: J2.9, U7.16 (PB6)
VIA1_PB7: J2.10, U7.17 (PB7)
VIA2_CA1: J3.11, U8.40 (CA1)
VIA2_CA2: J3.12, U8.39 (CA2)
VIA2_CB1: J4.11, U8.18 (CB1)
VIA2_CB2: J4.12, U8.19 (CB2)
VIA2_PA0: J3.3, U8.2 (PA0)
VIA2_PA1: J3.4, U8.3 (PA1)
VIA2_PA2: J3.5, U8.4 (PA2)
VIA2_PA3: J3.6, U8.5 (PA3)
VIA2_PA4: J3.7, U8.6 (PA4)
VIA2_PA5: J3.8, U8.7 (PA5)
VIA2_PA6: J3.9, U8.8 (PA6)
VIA2_PA7: J3.10, U8.9 (PA7)
VIA2_PB0: J4.3, U8.10 (PB0)
VIA2_PB1: J4.4, U8.11 (PB1)
VIA2_PB2: J4.5, U8.12 (PB2)
VIA2_PB3: J4.6, U8.13 (PB3)
VIA2_PB4: J4.7, U8.14 (PB4)
VIA2_PB5: J4.8, U8.15 (PB5)
VIA2_PB6: J4.9, U8.16 (PB6)
VIA2_PB7: J4.10, U8.17 (PB7)
VIA_SPI_MISO: U9.19 (CB2); also elsewhere on the board
VIA_SPI_MOSI: U9.16 (PB6); also elsewhere on the board
VIA_SPI_SCLK: U9.17 (PB7), U9.18 (CB1); also elsewhere on the board
/FT245R_RD: U9.12 (PB2); also elsewhere on the board
/RESET: J1.13, J2.13, J3.13, J4.13, U7.34 (~RESET), U8.34 (~RESET), U9.34 (~RESET); also elsewhere on the board
/VIA1: U7.23 (~CS2); also elsewhere on the board
/VIA1_IRQ: U7.21 (~IRQ); also elsewhere on the board
/VIA2: U8.23 (~CS2); also elsewhere on the board
/VIA2_IRQ: U8.21 (~IRQ); also elsewhere on the board
/VIA3: U9.23 (~CS2); also elsewhere on the board
/VIA3_IRQ: U9.21 (~IRQ); also elsewhere on the board
/VIA_SD_DETECT: U9.14 (PB4); also elsewhere on the board
/VIA_SPI_CS1: U9.15 (PB5); also elsewhere on the board
/W: U7.22 (R/~W), U8.22 (R/~W), U9.22 (R/~W); also elsewhere on the board

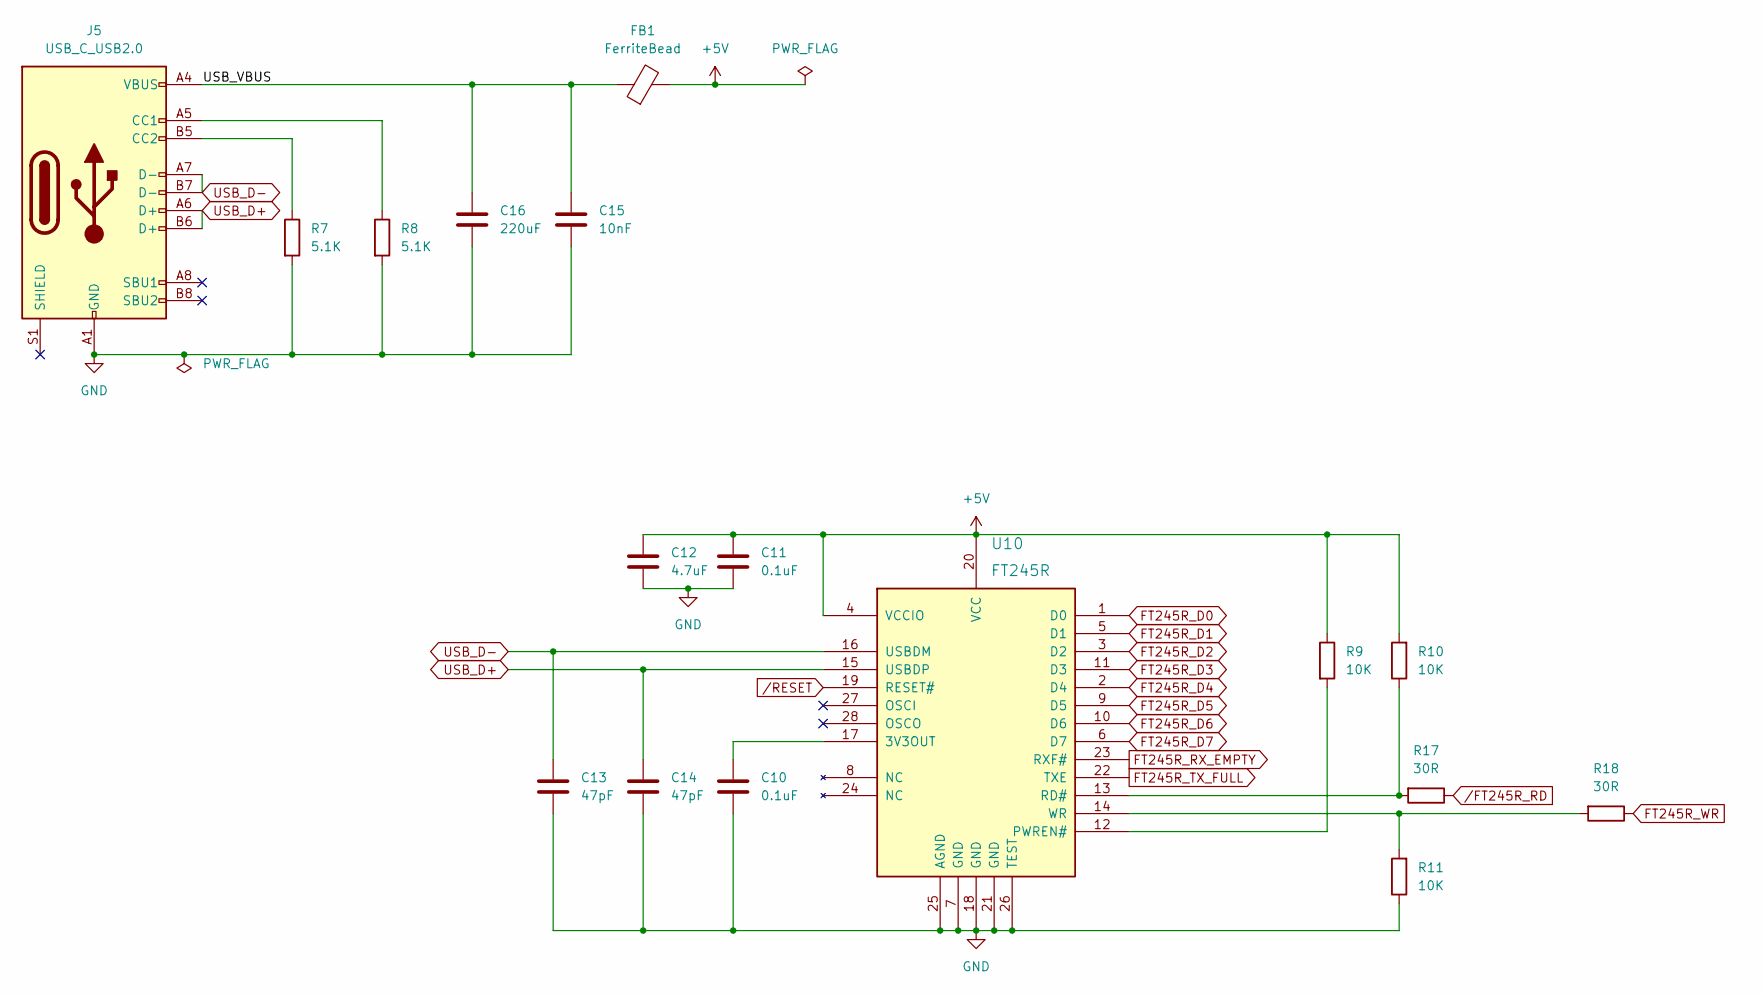
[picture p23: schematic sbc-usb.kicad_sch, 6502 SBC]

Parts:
C10, C11: 0.1uF; C_0805_2012Metric_Pad1.18x1.45mm_HandSolder
C12: 4.7uF; C_0805_2012Metric_Pad1.18x1.45mm_HandSolder
C13, C14: 47pF; C_0805_2012Metric_Pad1.18x1.45mm_HandSolder
C15: 10nF; C_0805_2012Metric_Pad1.18x1.45mm_HandSolder
C16: 220uF; CP_Radial_D6.3mm_P2.50mm
FB1: FerriteBead; R_0805_2012Metric_Pad1.20x1.40mm_HandSolder
J5: USB_C_USB2.0; USB_C_Receptacle_GCT_USB4085
R7, R8: 5.1K; R_0805_2012Metric_Pad1.20x1.40mm_HandSolder
R9, R10, R11: 10K; R_0805_2012Metric_Pad1.20x1.40mm_HandSolder
R17, R18: 30R; R_0805_2012Metric_Pad1.20x1.40mm_HandSolder
U10: FT245R; SSOP-28_5.3x10.2mm_P0.65mm

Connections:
+5V: C11.1, C12.1, FB1.2, R9.1, R10.2, U10.4 (VCCIO), U10.20 (VCC); also elsewhere on the board
/SBC-USB/USB_VBUS: C15.1, C16.1, FB1.1, J5.A4 (VBUS), J5.A9 (VBUS), J5.B4 (VBUS), J5.B9 (VBUS)
FT245R_D0: U10.1 (D0); also elsewhere on the board
FT245R_D1: U10.5 (D1); also elsewhere on the board
FT245R_D2: U10.3 (D2); also elsewhere on the board
FT245R_D3: U10.11 (D3); also elsewhere on the board
FT245R_D4: U10.2 (D4); also elsewhere on the board
FT245R_D5: U10.9 (D5); also elsewhere on the board
FT245R_D6: U10.10 (D6); also elsewhere on the board
FT245R_D7: U10.6 (D7); also elsewhere on the board
FT245R_RX_EMPTY: U10.23 (RXF#); also elsewhere on the board
FT245R_TX_FULL: U10.22 (TXE); also elsewhere on the board
FT245R_WR: R18.1; also elsewhere on the board
GND: C10.2, C11.2, C12.2, C13.2, C14.2, C15.2, C16.2, J5.A1 (GND), J5.A12 (GND), J5.B1 (GND), J5.B12 (GND), R7.2, R8.2, R11.1, U10.7 (GND), U10.18 (GND), U10.21 (GND), U10.25 (AGND), U10.26 (TEST); also elsewhere on the board
unnamed: C10.1, U10.17 (3V3OUT)
unnamed: J5.A5 (CC1), R8.1
unnamed: J5.B5 (CC2), R7.1
unnamed: R9.2, U10.12 (PWREN#)
unnamed: R10.1, R17.2, U10.13 (RD#)
unnamed: R11.2, R18.2, U10.14 (WR)
USB_D+: C14.1, J5.A6 (D+), J5.B6 (D+), U10.15 (USBDP)
USB_D-: C13.1, J5.A7 (D-), J5.B7 (D-), U10.16 (USBDM)
/FT245R_RD: R17.1; also elsewhere on the board
/RESET: U10.19 (RESET#); also elsewhere on the board

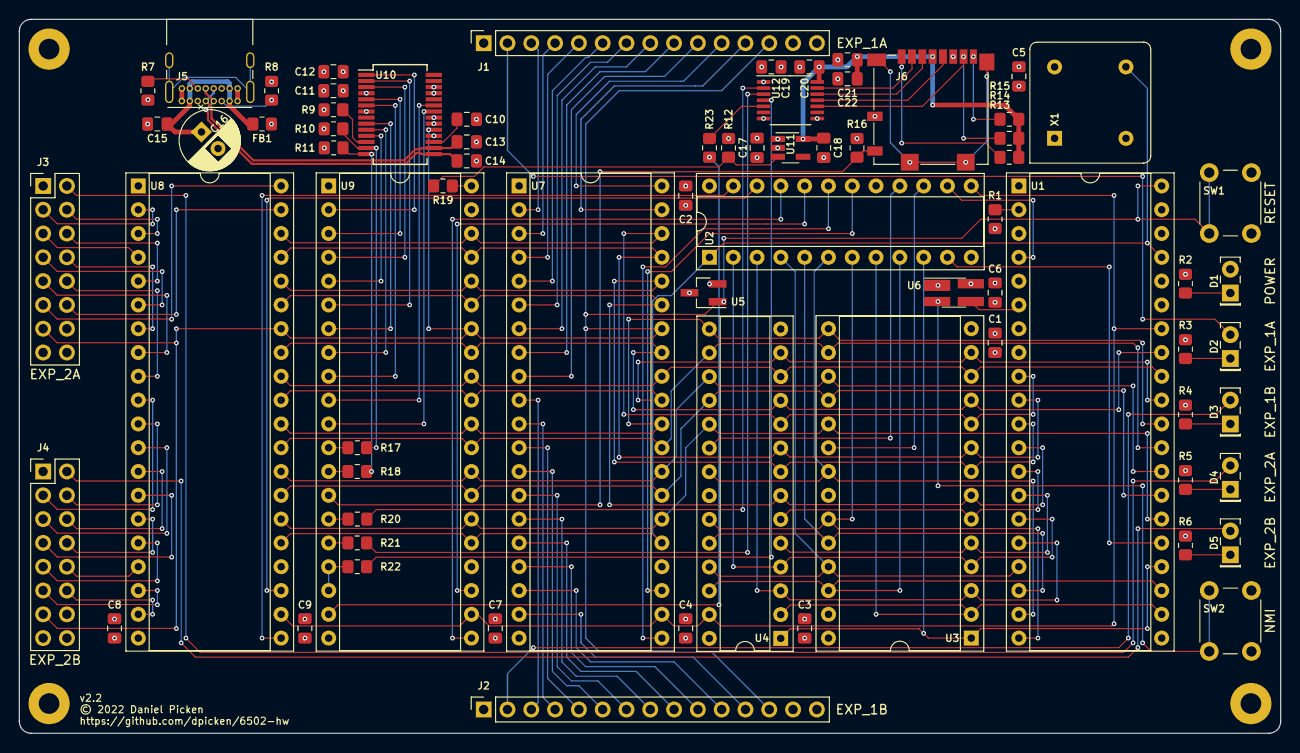
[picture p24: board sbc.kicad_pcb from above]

Board: 4 copper layers, 134.6 x 76.2 mm, 76 parts (0 on the bottom side), 129 nets.

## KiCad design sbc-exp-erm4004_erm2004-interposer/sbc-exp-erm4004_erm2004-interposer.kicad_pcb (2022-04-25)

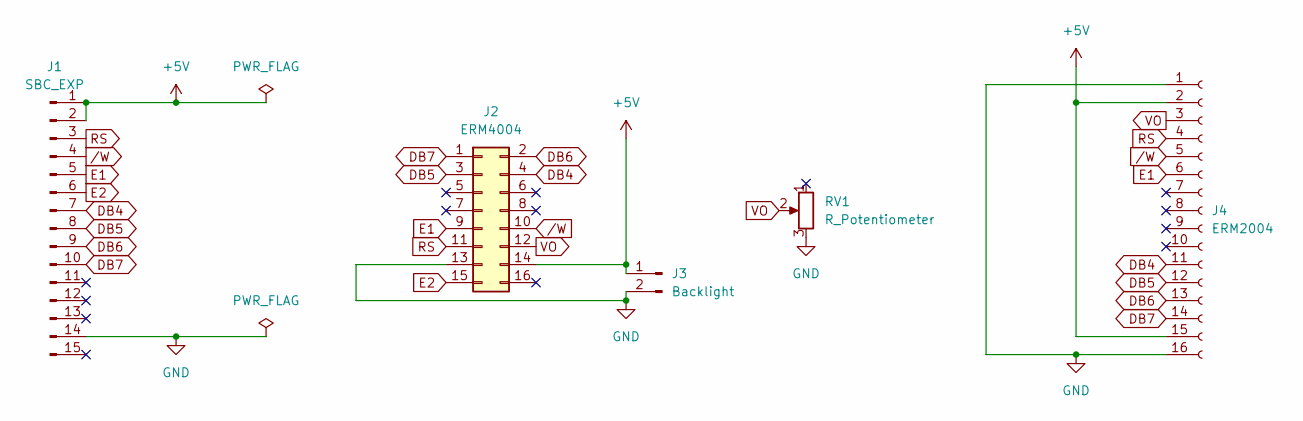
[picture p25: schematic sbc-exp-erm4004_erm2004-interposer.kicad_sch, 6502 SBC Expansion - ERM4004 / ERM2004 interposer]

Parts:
J1: SBC_EXP; PinHeader_1x15_P2.54mm_Vertical
J2: ERM4004; IDC-Header_2x08_P2.54mm_Vertical
J3: Backlight; PinHeader_1x02_P2.54mm_Horizontal
J4: ERM2004; PinSocket_1x16_P2.54mm_Vertical
RV1: R_Potentiometer; Potentiometer_Vishay_T73XW_Horizontal

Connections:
+5V: J1.1, J1.2, J2.14, J3.1, J4.2, J4.15
DB4: J1.7, J2.4, J4.11
DB5: J1.8, J2.3, J4.12
DB6: J1.9, J2.2, J4.13
DB7: J1.10, J2.1, J4.14
E1: J1.5, J2.9, J4.6
E2: J1.6, J2.15
GND: J1.14, J2.13, J3.2, J4.1, J4.16, RV1.3
RS: J1.3, J2.11, J4.4
VO: J2.12, J4.3, RV1.2
/W: J1.4, J2.10, J4.5

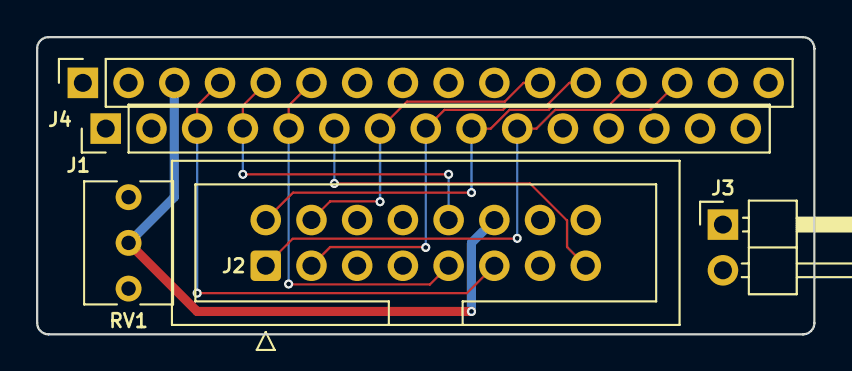
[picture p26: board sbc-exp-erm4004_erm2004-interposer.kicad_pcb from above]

Board: 4 copper layers, 43.2 x 16.5 mm, 5 parts (0 on the bottom side), 11 nets.

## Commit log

2021-07-29 Add kicad and 65xx chipset symbols
2021-07-30 Add SBC project and configure its libraries
    [sbc.kicad_pcb, sbc.sch]
2021-08-03 SBC: Wire up data and address buses
2021-08-03 SBC: Wire up glue logic
    [sbc.sch]
2021-08-03 SBC: Wire up power
    [sbc.sch]
2021-08-03 SBC: Wire up peripheral A and B connectors
    [sbc.sch]
2021-08-04 SBC: Wire up oscillator
    [sbc.sch]
2021-08-20 SBC: Power and reset
    [sbc.sch]
2021-09-01 SBC: Assign footprints
    [sbc.sch]
2021-09-10 SBC: Wire up memories
    [sbc.kicad_pcb, sbc.sch]
2021-09-10 SBC: Wire up signals
    [sbc.kicad_pcb]
2021-09-10 SBC: Wire up power and ground
    [sbc.kicad_pcb]
2021-09-10 SBC: Add mounting holes and polish silkscreen
    [sbc.kicad_pcb, sbc.sch]
2021-09-10 SBC: Add board outline
    [sbc.kicad_pcb]
2021-09-13 SBC: BOM
2021-09-16 SBC Controller: Add schematic and PCB
    [sbc-exp-control.kicad_pcb, sbc-exp-control.sch]
2021-09-17 SBC NH OLED interposer: Add schedmatic and PCB
    [sbc-exp-nh-oled-interposer.kicad_pcb, sbc-exp-nh-oled-interposer.sch]
2021-09-17 Add schematic PDFs
2021-09-21 SBC Controller: Work-around a missing resistor (for the controller's LED).
2021-10-12 Add a Kicad symbol for a tactile push button switch
2021-10-12 SBC: Fix v1.0 errata
    [sbc.kicad_pcb, sbc.sch]
2021-10-12 SBC Controller: Fix v1.0 errata
    [sbc-exp-control.kicad_pcb, sbc-exp-control.sch]
2021-10-12 SBC NH OLED interposer: v1.0 cleanup, no functional changes
    [sbc-exp-nh-oled-interposer.kicad_pcb]
2021-10-12 Regenerate schematic PDFs
2021-10-12 README.md: Update BOM for v1.1
2021-10-14 external/65xx: Create a local copy of the 65xx KiCad symbol library
    Preparatory step, prior to fixing the electrical type of the VIA and PIA GND pins.
    Copied pertinent files from https://github.com/mkeller0815/65xx_Library.
2021-10-14 external/65xx: Fix the electrical type of the VIA and PIA GND pins
    Output -> Power Input
2021-11-28 SBC v2.0
    Changes:
    - Second VIA
    - NMI button (hardware debounced)
    - 5 status LEDs (power and each VIA port)
    - Ground and power planes
    - Smaller footprint RAM and oscillator
    [sbc-exp-control.kicad_pcb, sbc-exp-control.sch, sbc-exp-nh-oled-interposer.kicad_pcb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]
2021-12-27 SBC USB Serial
    [sbc-exp-usb-serial.kicad_pcb, sbc-exp-usb-serial.sch]
2022-01-14 SBC v2.1
    Address some v2.0 errata:
    - SBC: Fix LED array layout
    - OLED interposer: Tidy silkscreen
    [sbc-exp-nh-oled-interposer.kicad_pcb, sbc.kicad_pcb]
2022-03-05 KiCad 6 symbols and footprints
2022-04-25 SBC v2.2
    Changes over v2:
    - Address space decode and IRQ glue logic moved into a PLD
    - Adds serial port and power via USB-C connector
    - Adds onboard microSD mass storage
    [sbc-exp-control.kicad_pcb, sbc-exp-control.kicad_sch, sbc-exp-control.sch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]
2023-04-19 SBC v2.3
    Fixes over v2.2:
    - SBC: Fix the VIA footprint: CA1 and CB1 are inputs
    - SBC: Move the microSD power enable line from (VIA3) CA1 (input) to CA2 (output)
    - SBC: Tie 65C02 SOB high
    - Controller: connect LED enable
    - Controller: SMT switches
    [sbc-exp-control.kicad_pcb, sbc-exp-control.kicad_sch, sbc-sd.kicad_sch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]

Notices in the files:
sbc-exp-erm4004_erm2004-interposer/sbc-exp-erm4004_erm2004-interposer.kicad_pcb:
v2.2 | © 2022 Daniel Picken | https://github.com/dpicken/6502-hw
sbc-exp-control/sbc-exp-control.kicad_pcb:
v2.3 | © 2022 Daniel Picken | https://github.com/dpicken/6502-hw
